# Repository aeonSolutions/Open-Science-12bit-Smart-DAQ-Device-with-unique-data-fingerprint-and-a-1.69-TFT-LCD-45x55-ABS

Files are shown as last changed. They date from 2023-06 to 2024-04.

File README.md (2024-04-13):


 
<a href="https://github.com/sponsors/aeonSolutions">
   
</a>

**Unique Visits** <a href="https://trackgit.com"> trackgit-views </a>



 
</p>

[PCB-Prototyping-Catalogue](https://github.com/aeonSolutions/PCB-Prototyping-Catalogue)  >>  [Laboratory Automation](https://github.com/aeonSolutions/PCB-Prototyping-Catalogue/tree/main/Laboratory%20Automation)  >>  [Smart DAQ](https://github.com/aeonSolutions/PCB-Prototyping-Catalogue/tree/main/Smart%20DAQ)  >> [12-bit Smart DAQs](https://github.com/aeonSolutions/PCB-Prototyping-Catalogue/tree/main/Smart%20DAQ/12-bit) >> 12-bit Smart DAQ Device with unique data fingerprint and a 1.69" TFT LCD  45x55 ABS

<br>

# 12bit Smart DAQ Device with unique data fingerprint and a 1.69" TFT LCD  45x55 ABS
This is the repository for revision of the 12-bit Smart DAQ Device with a unique data fingerprint able to do experimental data upload to any data repository. 

<br>

<p align="center">
<strong> <a href="https://aeonsolutions.github.io/sponsor/sdad/2ch/">Interactive view of the PCB Layout</a> </strong> &nbsp;
  <strong> <a href="https://aeonsolutions.github.io/sponsor/sdad/2ch/circuit_schematic.html">Interactive view of the circuit schematic</a> </strong> <br>
 <sup>Click to view the latest revision</sup>
</p>

<br>

Here one can find the following hardware electronics revisions:
- SDAD rev. 01-2023
- SDAD rev. 02-2023
- SDAD rev. 03-2023
- SDAD rev. 03-2023 B
- SDAD rev. 09-2023
- SDAD rev. 10-2023

<p align="center">
   
</p>

####  Status: Tested. Require improvements. 

**Known faults:**
- PCB copper track optimizations
- components rearrangement for optimization of PCB track inductance 

<br>
 
## Dataverse API C library

This device uses my C++ library to expedite dataverse API integration on smart DAQ devices or elsewhere. Follow the link to its repository:

https://github.com/aeonSolutions/OpenScience-Dataverse-API-C-library

<p align="center">
<a href="https://github.com/aeonSolutions/OpenScience-Dataverse-API-C-library"> 
     
</a>
</p>

<br>
<br>

The photo above is one of the many specimens I purposely fabricated to research self-sensing properties of asphalt mixed with a known content of carbon fibers. This is a 10cm cylinder specimen and on the top is already setup my own design smart #DAQ (get it here on my GitHub ) with the ability to upload LIVE experimental data to a #dataverse.

In the photo above the smart DAQ is installed on an acrylic case and screwed with plastic screws to an acrylic base with the same cross-section area as the specimen to be tested. 
The acrylic base can be bought [here](https://s.click.aliexpress.com/e/_DEGsZaL). And the acrylic case [here](https://s.click.aliexpress.com/e/_Dmudkjt). 

<br>

## CE Ready Logo
This hardware is ready to get a CE marking. To learn more about this marking goto to [Wikipedia here](https://en.wikipedia.org/wiki/CE_marking).

<p align="center">
   
</p>

<br>

### Smart PCB Hardware Specifications
The hardware specifications for the 12bit pcb with dimensions of 23.5x43.5mm can be found [here](https://github.com/aeonSolutions/openScience-Smart-DAQ-to-Upload-Live-Experimental-Data-to-a-Data-Repository/wiki/Smart-DAQ-Specifications).

 **In real life this smart DAQ is able to:**
- connect to all kinds of 3V to 5V Digital sensors;
- connect to all kinds of sensors compatible with the I2C protocol. (max 118 sensors simultaneously)
- measure voltage in the range of  [0;3.3V]
- measure electrical resistance [0; 10^6] Ohm 
- do temperature and humidity compensation on all measurements 
- has a voltage reference sensor for improved accuracy on ADC measurements  
- has a motion sensor to know if anyone moved a specimen during an experiment
- ability to show live experimental data on the 1.69-inch TFT IPS LCD  

<br>
<br>

## PCB circuit Schematic 
The PCB circuit schematic is available in PDF located in the folder "PCB Schematic"
<br>

## KiCad project files
The project files in KiCad are located in the folder "KiCad".
<br>

<p align="center">
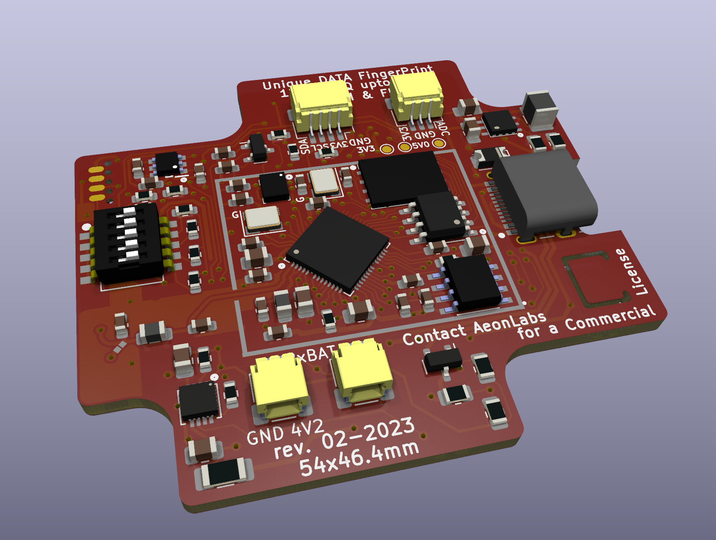
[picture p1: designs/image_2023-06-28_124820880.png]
  
</p>

<br>

## Proof of Concept

To test and validate proposed smart DAQ PCB electronics and its firmware as a solution for LIVE experimental data measurements on any test specimen part of a experimental campaign, This PCB electronics is being used to measure a predefined set of variables/parameters to further study several asphalt mixtures with known carbon fiber weight content in the asphalt matrix. Below is a YouTube link to an unedited short video showing one of the experimental setups.

<p align="center">
   <a href="https://youtu.be/eOA1JPgop0k">
      
   </a> <br>
 <sup>Video on Youtube</sup>
</p>

## Join the Beta Program
Join the beta program to test and debug to provide feedback, ideas, modifications, suggestions, improvements. And in return, write your own article blog or post on social media about it. See participation conditions on the [Wiki](https://github.com/aeonSolutions/PCB-Prototyping-Catalogue/wiki/Beta-Participation-Agreement).  

## Contributing

Bug reports and pull requests are welcome on any of AeonLabs repositories. This project is intended to be a safe, welcoming space for collaboration, and contributors are expected to adhere to the [code of conduct](https://github.com/aeonSolutions/OpenScience-Dataverse-API-C-library/blob/main/CODE_OF_CONDUCT.md).

- Contributing
  - [Your Contributions Matter](https://github.com/aeonSolutions/PCB-Prototyping-Catalogue/wiki/Your-Contributions-Matter)
  - [Contributor Code of Conduct](https://github.com/aeonSolutions/PCB-Prototyping-Catalogue/wiki/Contributor-Code-of-Conduct)

<br>

**[Beta Participation Agreement](https://github.com/aeonSolutions/PCB-Prototyping-Catalogue/wiki/Beta-Participation-Agreement)**

The Beta Participant Agreement is a legal document being executed between you and AeonLabs that outlines the conditions when participating in the Beta Program.

## Coding standards

Please make sure tests pass before committing, and add new tests for new additions.

- Licensing 
  - [AeonLabs Solutions for Open Hardware & Source Development](https://github.com/aeonSolutions/PCB-Prototyping-Catalogue/wiki/AeonLabs-Solutions-for-Open-Hardware-&-Source-Development)

<br>
<br>

## Author

You can get in touch with me on my LinkedIn Profile:

#### Miguel Tomas



You can also follow my GitHub Profile to stay updated about my latest projects: 

<br>

### Be supportive of my dedication and work towards technology education and buy me a cup of coffee
The PCB Desgin Files i provide here for anyone to use are free. If you like this Smart Device or use it, please consider buying me a cup of coffee, a slice of pizza or a book to help me study, eat and think new PCB design files.

<p align="center">
    <a href="https://www.buymeacoffee.com/migueltomas">
        
    </a>
</p>

### Make a donation on Paypal
Make a donation on paypal and get a TAX refund*.

<p align="center">
    <a href="http://paypal.me/mtpsilva">
        
    </a>
</p>

### Support all these open hardware projects and become a Github sponsor  
Liked any of my PCB KiCad Designs? Help and Support my open work to all by becomming a Github sponsor.

<p align="center">
    <a href="https://github.com/aeonSolutions/PCB-Prototyping-Catalogue/blob/main/become_a_sponsor/aeonlabs-github-sponsorship-agreement.docx">
        
    </a>
    <a href="https://github.com/sponsors/aeonSolutions">
        
    </a>
</p>

# 

### License

Before proceeding to download any of AeonLabs software solutions for open-source development and/or PCB hardware electronics development make sure you are choosing the right license for your project. See [AeonLabs Solutions for Open Hardware & Source Development](https://github.com/aeonSolutions/PCB-Prototyping-Catalogue/wiki/AeonLabs-Solutions-for-Open-Hardware-&-Source-Development) for more information.

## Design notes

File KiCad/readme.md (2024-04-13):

[PCB-Prototyping-Catalogue](https://github.com/aeonSolutions/PCB-Prototyping-Catalogue)  >>  [Laboratory Automation](https://github.com/aeonSolutions/PCB-Prototyping-Catalogue/tree/main/Laboratory%20Automation)  >>  [Smart DAQ](https://github.com/aeonSolutions/PCB-Prototyping-Catalogue/tree/main/Smart%20DAQ)  >> [12-bit Smart DAQs](https://github.com/aeonSolutions/PCB-Prototyping-Catalogue/tree/main/Smart%20DAQ/12-bit) >> 12-bit Smart DAQ Device with unique data fingerprint and a 1.69" TFT LCD  45x55 ABS

<div align="right">
 <a href="https://github-com.translate.goog/aeonSolutions/Open-Science-12bit-Smart-DAQ-Device-with-unique-data-fingerprint-and-a-1.69-TFT-LCD-45x55-ABS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">Change language</a>  <br>
Last change 13-04-2024
</div>

<br>

This folder contains the KiCad Project files, for the hardware electronics of the S.D.A.D.  Each KiCad project is available with a [creative commons share alike non-commercial license](https://creativecommons.org/licenses/by-nc-sa/4.0/deed.en) . 

<p align="center">
  <strong> <a href="https://aeonsolutions.github.io/portfolio/hardware_electronics/laboratory/">Interactive web view of the PCB Layout</a> </strong> <br>
 <sup>Click to view the latest revision of the PCB Layout</sup>
</p>

However, they're not fully complete. If you like it and are looking to use it on your projects, you can download the complete Kicad project files with a one-time donation, [click here](https://github.com/sponsors/aeonSolutions) to learn how,  and don't forget to include it in a message the name of the module/hardware electronics you need. <br> Thank you 🙏.

### Support all these open hardware projects and become a GitHub sponsor  
Did you like any of my PCB KiCad Designs? Help and Support my open work to all by becoming a GitHub sponsor.

<p align="center">
    <a href="https://github.com/aeonSolutions/PCB-Prototyping-Catalogue/blob/main/become_a_sponsor/aeonlabs-github-sponsorship-agreement.docx">
        
    </a>
    <a href="https://github.com/sponsors/aeonSolutions">
        
    </a>
</p>

#

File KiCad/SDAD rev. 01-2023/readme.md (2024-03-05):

[PCB-Prototyping-Catalogue](https://github.com/aeonSolutions/PCB-Prototyping-Catalogue)  >>  [Laboratory Automation](https://github.com/aeonSolutions/PCB-Prototyping-Catalogue/tree/main/Laboratory%20Automation)  >>  [Smart DAQ](https://github.com/aeonSolutions/PCB-Prototyping-Catalogue/tree/main/Smart%20DAQ)  >> [12-bit Smart DAQs](https://github.com/aeonSolutions/PCB-Prototyping-Catalogue/tree/main/Smart%20DAQ/12-bit) >> 12-bit Smart DAQ Device with unique data fingerprint and a 1.69" TFT LCD  45x55 ABS

<div align="right">
 <a href="https://github-com.translate.goog/aeonSolutions/Open-Science-12bit-Smart-DAQ-Device-with-unique-data-fingerprint-and-a-1.69-TFT-LCD-45x55-ABS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">Change language</a>  <br>
Last change 05-03-2024
</div>

<br>

This folder contains the KiCad Project files, for the hardware electronics of the S.D.A.D.  Each KiCad project is available with a [creative commons share alike non-commercial license](https://creativecommons.org/licenses/by-nc-sa/4.0/deed.en) . 

<p align="center">
  <strong> <a href="https://aeonsolutions.github.io/sponsor/sdad/2ch/">Interactive web view of the PCB Layout</a> </strong> <br>
 <sup>Click to view the latest revision of the PCB Layout</sup>
</p>

If you like it and use it on your own hardware designs please support this project, [click here](https://github.com/sponsors/aeonSolutions) to learn how. <br> Thank you 🙏. 

### Support all these open hardware projects and become a GitHub sponsor  
Liked any of my PCB KiCad Designs? Help and Support my open work to all by becoming a GitHub sponsor.

<p align="center">
    <a href="https://github.com/aeonSolutions/PCB-Prototyping-Catalogue/blob/main/become_a_sponsor/aeonlabs-github-sponsorship-agreement.docx">
        
    </a>
    <a href="https://github.com/sponsors/aeonSolutions">
        
    </a>
</p>

#

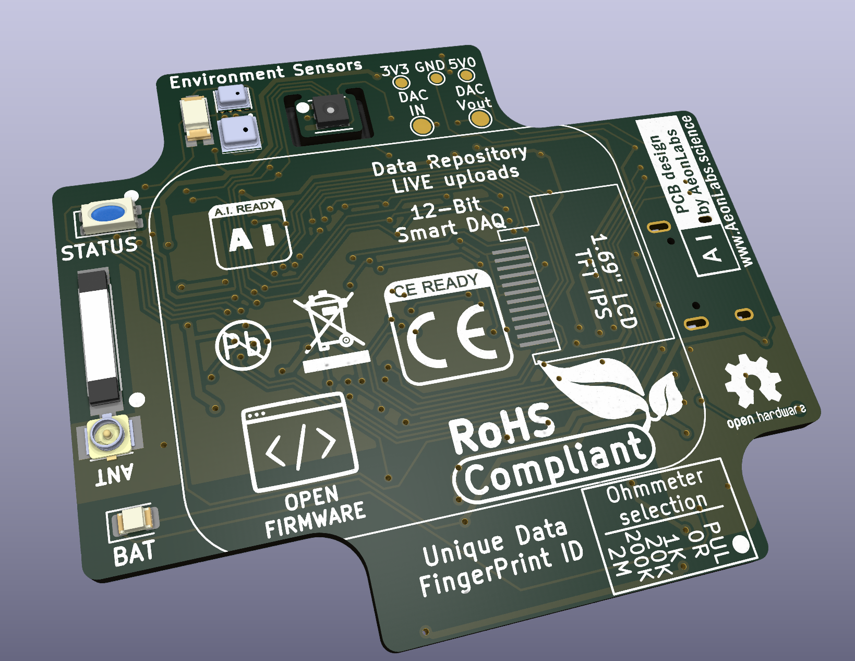
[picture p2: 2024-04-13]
media/revision_10_2023_12bit_lcd.png

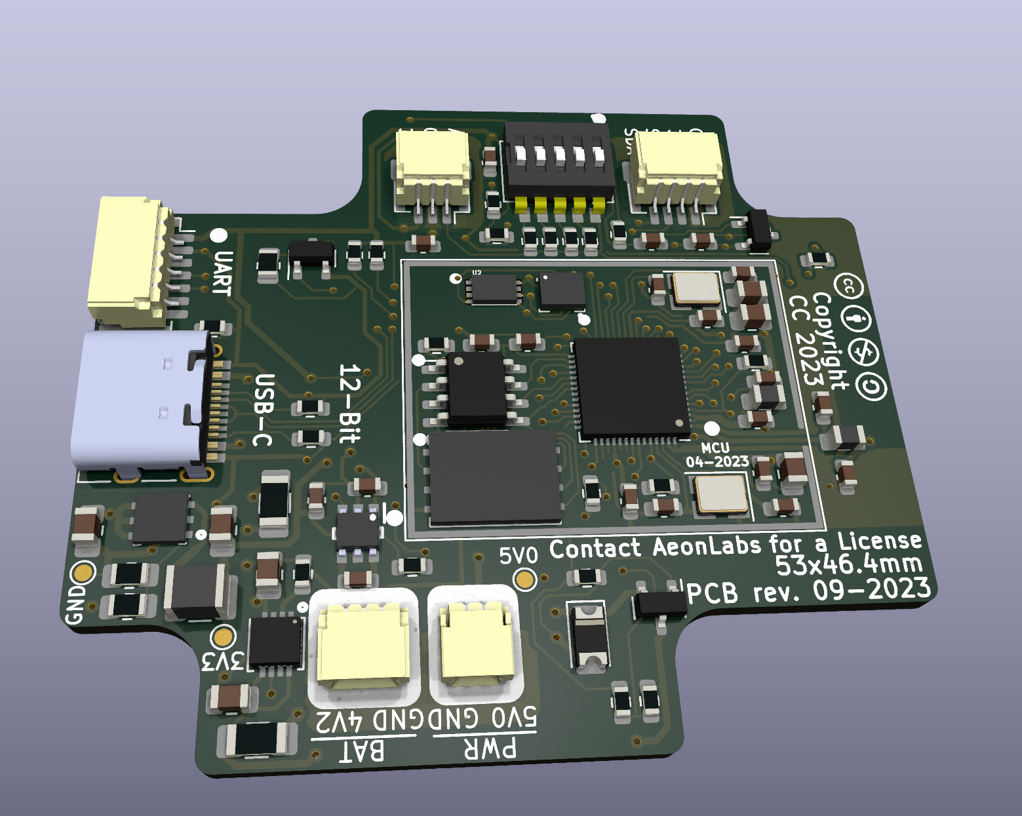
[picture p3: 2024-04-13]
media/revision_10_2023_12bit.png

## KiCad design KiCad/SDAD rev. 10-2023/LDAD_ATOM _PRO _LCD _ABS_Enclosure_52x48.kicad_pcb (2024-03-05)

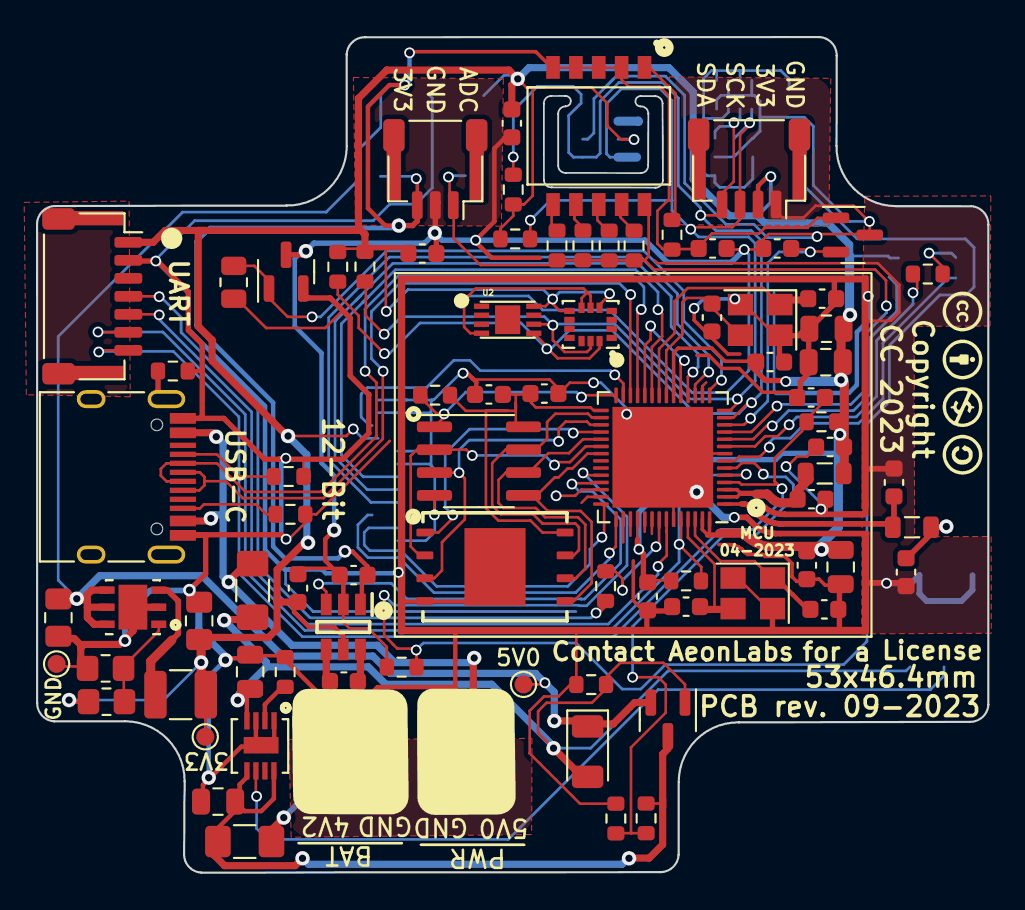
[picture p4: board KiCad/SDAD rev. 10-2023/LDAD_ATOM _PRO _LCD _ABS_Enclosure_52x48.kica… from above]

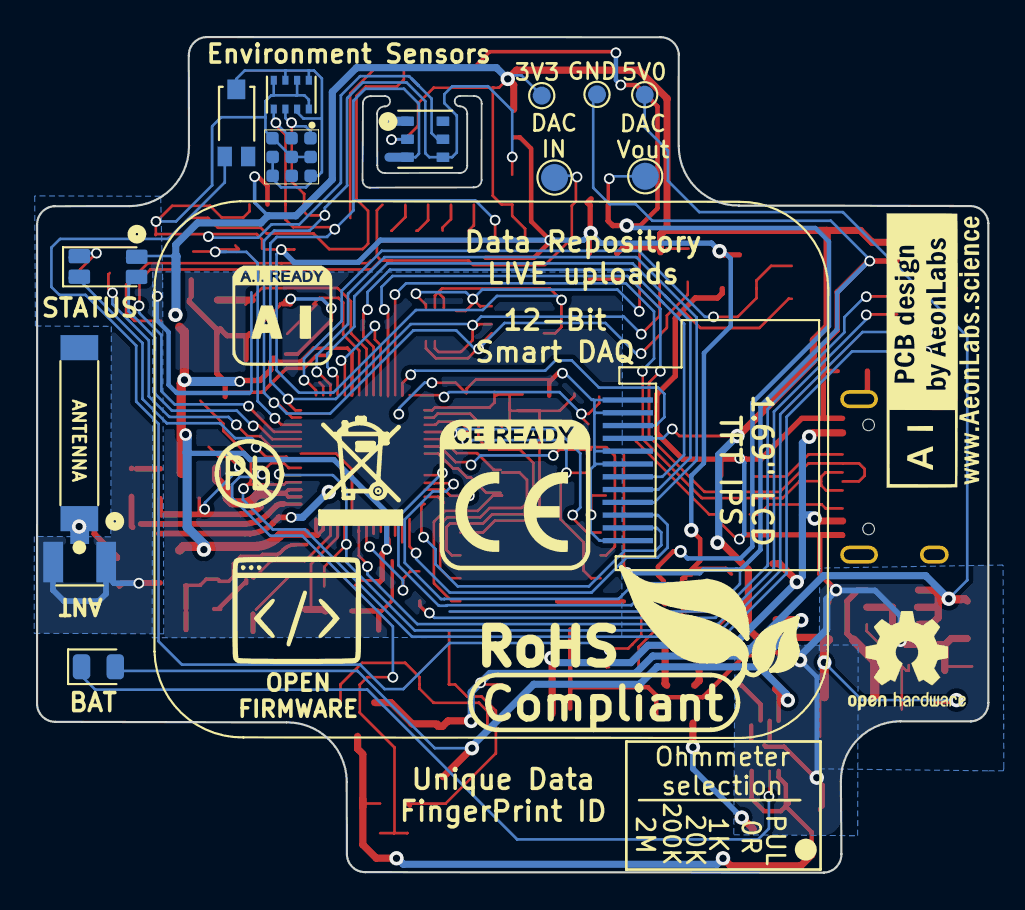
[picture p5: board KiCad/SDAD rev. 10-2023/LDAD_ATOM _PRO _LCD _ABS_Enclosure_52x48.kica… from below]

Board: 2 copper layers, 52.9 x 46.4 mm, 98 parts (15 on the bottom side), 64 nets.

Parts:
ATH20_C1: 100nF; C_0603_1608Metric
ATSHA_C1: 100nF; C_0603_1608Metric
AUR1: AUR9718x_DFN_3x3mm_6_pin; AUR9718 ST1S09 SON95P300X300X100-7N
AUR_C1: 22uF; C_0805_2012Metric_Pad1.18x1.45mm_HandSolder
AUR_C2: 4.7uF; C_0805_2012Metric_Pad1.18x1.45mm_HandSolder
AUR_R1: 75k; R_0805_2012Metric_Pad1.20x1.40mm_HandSolder
AUR_R2: 24k; R_0805_2012Metric_Pad1.20x1.40mm_HandSolder
AUR_l1: 3.3uF; L_1210_3225Metric
BAT_FUSE1: Polyfuse; Fuse_1206_3216Metric_Pad1.42x1.75mm_HandSolder
BAT_SENSE_R1, BAT_SENSE_R2: 100k; R_0603_1608Metric
CN3065_C2: 4.7uF; C_0805_2012Metric
CN3065_R1: 1K8; R_0603_1608Metric
CN3065_STDBY_LED1: LED; LED_0805_2012Metric
CN3965_C1: 22uF; C_0805_2012Metric
DIPSW1: Conn_02x05_Odd_Even; Dip Switch 5pin 1mm SW_DS05-127-2-06BK-SMT-TR
DIP_R1: 4k7; R_0603_1608Metric
DIP_R2: 1k; R_0603_1608Metric
DIP_R3: 20k; R_0603_1608Metric
DIP_R4: 200k; R_0603_1608Metric
DIP_R5: 2M; R_0603_1608Metric
DMP1045U_1: DMP1045U; SOT-23
DMP1045_R1: 10K; R_0603_1608Metric
DMP1045_SCHOT1: D_Schottky; D_1206_3216Metric
EPS1: ESP32-PSRAM_LY68L6400S; SOIC-8_3.9x4.9mm_P1.27mm
ESP32S1: ESP32-S3; QFN-56-1EP_7x7mm_P0.4mm_EP5.6x5.6mm
ESP32_SHIELD1: RFShield_OnePiece; ESP32-S3 GND Shield
ESP_FLASH1: W25Q128JVS; WSON8 FLASH SPI SON127P800X600X80-9N
E_DTR_R1: 10k; R_0603_1608Metric
E_LNA_ANT1: AN9520; 2.4ghZ WIFI ANTENNA AN9520_ANT2-SMD-9.5X2.1X1.0MM
E_LNA_ANT2: U.FL-R-SMT(01); RF Antenna IPEX SMD PCB HRS_U.FL-R-SMT(01)
E_LNA_C1, E_LNA_C2: 2.7pF; C_0603_1608Metric
E_LNA_l1: 1.8nH 5%; L_0805_2012Metric
E_RTS_C1: 100nF; C_0603_1608Metric
E_RTS_R1: 10k; R_0603_1608Metric
E_SPI_C1: 1uF 10% 50V; C_0603_1608Metric
E_SPI_C2: 100nF 10% 16V; C_0603_1608Metric
E_UART_TX_1: 499R; R_0603_1608Metric
E_VDDA_C1: 100nF; C_0603_1608Metric
E_VDDA_C2: 1uF 10% 50V; C_0805_2012Metric
E_VDD_3_C1, E_VDD_3_C2: 10uF 20% 6.3V; C_0805_2012Metric
E_VDD_3_C3, E_VDD_3_C4: 100nF 10% 16V; C_0603_1608Metric
E_VDD_CPU_C1: 100nF 10% 16V; C_0603_1608Metric
E_VDD_L1: 12nH 5%; L_0805_2012Metric
E_VDD_RTC_C1: 100nF 10% 16V; C_0603_1608Metric
E_XTAL32_1: 32.768Mhz 22pF+-10PPM; Crystal_SMD_3225-4Pin_3.2x2.5mm
E_XTAL32_C1, E_XTAL32_C2, E_XTAL40_C1, E_XTAL40_C2: 22pF 5% 50V; C_0603_1608Metric
E_XTAL40_1: 40Mhz 22pF+-10PPM; Crystal_SMD_3225-4Pin_3.2x2.5mm
ExtSW1: Conn_01x03_Female; JST_SH_SM03B-SRSS-TB_1x03-1MP_P1.00mm_Horizontal
ExtSWBAT_PLUG2: Conn_01x03_Female; JST_SH_SM03B-SRSS-TB_1x03-1MP_P1.00mm_Horizontal
HX1: HX4002; HX4002 SOT95 P280X125-6N
HX_C1, HX_C2, HX_C3: 2.2uF; C_0603_1608Metric
I2C_PLUG1: I2C6; JST_SH_SM04B-SRSS-TB_1x04-1MP_P1.00mm_Horizontal
I2C_SCL_R1, I2C_SDA_R1: 10k; R_0603_1608Metric
IC_ENS1: ENS160 Gas Semsor
IMR1, IMR2: 10K; R_0603_1608Metric
IMU1: LSM6DS3; LSM6DS3 Motion Sensor PQFN50P300X250X86-14N
J1: TYPE-C-31-M-12; USB_C_Receptacle_HRO_TYPE-C-31-M-12
JICSP1: Conn_01x07_Socket; JST_SH_SM07B-SRSS-TB_1x07-1MP_P1.00mm_Horizontal
LCD1: Conn_01x12_Male; 1,69 inch LCD IPS TFT
LED1: LED_GBRC; LED_1206_3210_RGB_Metric
LR1: 330R; R_0603_1608Metric
MTRR1: 10k; R_0805_2012Metric
MTRT1: NPN; SOT-23
PSRAM_R1: 100K; R_0603_1608Metric
PWR_FUSE1: Polyfuse; Fuse_1206_3216Metric_Pad1.42x1.75mm_HandSolder
PWR_PLUG1: Screw_Terminal_01x02; JST_SH_SM02B-SRSS-TB_1x02-1MP_P1.00mm_Horizontal
Sign-PbFree: LOGO_PBFREE
Sign-RecycleBin: LOGO_RECYCLEBIN_1
Sign-RoHS: LOGO_ROHS_1
TMPR1: 10K; R_0603_1608Metric
TP1, TP1#2: VIN; TestPoint_Pad_D1.0mm
TP2, TP2#2: VOut; TestPoint_Pad_D1.0mm
TP3, TP3#2: GND; TestPoint_Pad_D1.0mm
U1: MCP1525-TT; SOT-23
U2: ATSHA204A-MAHDA-T; ATSHA204 UDFN-8 DFN200X300X60-9N
U3: Battery_charger_CN3065_QFN8; QFN8 3.1x2.9mm QFNn-8 3x3 SON80P400X400X100-9N
U4: AHT20; AHT20 HT Sensor PSON100P300X300X110-6N
U5: BMP280; XDCR_BMP280
U6: TEMT6000; TEMT6000-SEN
USB_PLUG_R1, USB_PLUG_R3: 5k1; R_0603_1608Metric
USB_PLYG_R2: 150K; R_0603_1608Metric
VOLTAGE_REF_C1, VOLTAGE_REF_C2: 100nF; C_0603_1608Metric

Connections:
3V3: ATH20_C1.2, ATSHA_C1.2, AUR_C1.1, AUR_R1.1, AUR_l1.1, ESP32S1.20 (VDD3P3_RTC), ESP32S1.46 (VDD3P3_CPU), ESP32S1.55 (VDDA), ESP32S1.56 (VDDA), E_DTR_R1.1, E_RTS_R1.1, E_VDDA_C1.2, E_VDDA_C2.2, E_VDD_3_C1.1, E_VDD_3_C2.1, E_VDD_3_C3.1, E_VDD_CPU_C1.1, E_VDD_L1.1, E_VDD_RTC_C1.1, HX1.5 (VIN), HX_C3.2, I2C_PLUG1.2, I2C_SCL_R1.1, I2C_SDA_R1.2, IC_ENS1.4 (VDD), IC_ENS1.5 (VDDIO), IC_ENS1.7 (CS), IMR1.1, IMR2.1, IMU1.5 (VDDIO), IMU1.8 (VDD), JICSP1.1, LCD1.4, LED1.4 (K), TP2.1, TP2#2.1, U2.8 (VCC), U4.2 (VDD), U5.2 (CSB), U5.6 (VDDIO), U5.8 (VDD), U6.COLLECTOR
3V3_PLUG: DIPSW1.3, DIPSW1.5, DIPSW1.7, DIPSW1.9, DIP_R1.2, ExtSW1.3, HX1.1 (VOUT), HX_C1.1, U1.1 (Vin), VOLTAGE_REF_C1.2
ADC_IN_IO04: DIPSW1.2, DIP_R2.1, DIP_R3.1, DIP_R4.1, DIP_R5.1, ESP32S1.11 (GPIO6/ADC1_CH5), ExtSW1.1
BAT_SENSE_IO21: BAT_SENSE_R1.1, BAT_SENSE_R2.2, ESP32S1.6 (GPIO1/ADC1_CH0)
CHIP_EN: ESP32S1.4 (CHIP_PU/RESET), E_RTS_C1.2, E_RTS_R1.2, JICSP1.7
DAC_CALIBRATION: ESP32S1.19 (GPIO14/ADC2_CH3), ESP32S1.24 (GPIO18/ADC2_CH7/DAC_1)
ESP_GPIO0_BOOT-DTR: ESP32S1.5 (GPIO0/BOOT), ESP32S1.52 (GPIO46), E_DTR_R1.2, JICSP1.6
GND: AUR1.2 (GND), AUR1.7 (GND), AUR_C1.2, AUR_C2.2, AUR_R2.2, BAT_SENSE_R1.2, CN3065_C2.1, CN3065_R1.1, CN3965_C1.1, DMP1045_R1.2, EPS1.4 (VSS), ESP32S1.8 (GPIO3/ADC1_CH2), ESP32S1.51 (GPIO45), ESP32S1.57 (GND), ESP32_SHIELD1.1 (Shield), ESP_FLASH1.4 (GND), ESP_FLASH1.9 (GND), E_LNA_ANT2.1 (GND), E_LNA_ANT2.2 (GND), E_LNA_C1.2, E_LNA_C2.2, E_RTS_C1.1, E_SPI_C1.2, E_SPI_C2.2, E_VDDA_C1.1, E_VDDA_C2.1, E_VDD_3_C1.2, E_VDD_3_C2.2, E_VDD_3_C3.2, E_VDD_3_C4.2, E_VDD_CPU_C1.2, E_VDD_RTC_C1.2, E_XTAL32_1.2, E_XTAL32_1.4, E_XTAL32_C1.2, E_XTAL32_C2.2, E_XTAL40_1.2, E_XTAL40_1.4, E_XTAL40_C1.2, E_XTAL40_C2.2, ExtSWBAT_PLUG2.3, J1.B1, J1.B12, JICSP1.2, LCD1.1, LCD1.2, LCD1.5, LCD1.6, LCD1.12, MTRR1.1, MTRT1.2, PWR_PLUG1.1, TP3.1, TP3#2.1, U3.1 (V_Temp), U3.3 (GND), U3.9 (GND), USB_PLUG_R1.2, USB_PLUG_R3.2, USB_PLYG_R2.2
GNDD: ATH20_C1.1, ATSHA_C1.1, ExtSW1.2, HX1.2 (GND), HX_C1.2, HX_C3.1, I2C_PLUG1.1, IC_ENS1.3 (MISO), IC_ENS1.8 (VSS), IC_ENS1.9 (VSS), IMU1.6 (GND), IMU1.7 (GND), MTRT1.3, TMPR1.1, U1.3 (Vss), U2.4 (GND), U4.5 (GND), U5.1 (GND), U5.5 (SDO), U5.7 (GND), VOLTAGE_REF_C1.1, VOLTAGE_REF_C2.1
GPIO8_I2C_SDA: ESP32S1.13 (GPIO8/ADC1_CH7), I2C_PLUG1.4, I2C_SDA_R1.1, IC_ENS1.1 (SDA), IMR1.2, IMU1.14 (SDA), U2.5 (SDA), U4.4 (SDA), U5.3 (SDI)
GPIO9_I2C_SCL: ESP32S1.14 (GPIO9/ADC1_CH8), I2C_PLUG1.3, I2C_SCL_R1.2, IC_ENS1.2 (SCL), IMR2.2, IMU1.13 (SCL), U2.6 (SCL), U4.3 (SCL), U5.4 (SCK)
LCD_CS_IO13: ESP32S1.18 (GPIO13/ADC2_CH2), LCD1.8
LCD_DC_IO17: ESP32S1.23 (GPIO17/ADC2_CH6/DAC_2), LCD1.7
LCD_I2C_SCL_IO12: ESP32S1.17 (GPIO12/ADC2_CH1), LCD1.9
LCD_I2C_SDA_IO38: ESP32S1.43 (GPIO38), LCD1.10
LCD_LED_IO21: ESP32S1.27 (GPIO21), LCD1.3
LCD_RST_IO37: ESP32S1.42 (GPIO37), LCD1.11
LED_B_IO05: ESP32S1.10 (GPIO5/ADC1_CH4), LED1.2 (BA)
LED_G_IO02: ESP32S1.7 (GPIO2/ADC1_CH1), LED1.1 (GA)
LED_R_IO04: ESP32S1.9 (GPIO4/ADC1_CH3), LR1.1
unnamed: AUR1.1 (FB), AUR_R1.2, AUR_R2.1
unnamed: AUR1.3 (SW), AUR_l1.2
unnamed: DIPSW1.1, DIP_R1.1
unnamed: DIPSW1.4, DIP_R2.2
unnamed: DIPSW1.6, DIP_R3.2
unnamed: DIPSW1.8, DIP_R4.2
unnamed: DIPSW1.10, DIP_R5.2
unnamed: ESP32S1.21 (GPIO15/ADC2_CH4/XTAL_32K_P), E_XTAL32_1.3, E_XTAL32_C1.1
unnamed: ESP32S1.22 (GPIO16/ADC2_CH5/XTAL_32K_N), E_XTAL32_1.1, E_XTAL32_C2.1
unnamed: ESP32S1.1 (LNA_IN/RF), E_LNA_C2.1, E_LNA_l1.2
unnamed: ESP32S1.49 (U0TXD/PROG/GPIO43), E_UART_TX_1.2
unnamed: ESP32S1.2 (VDD3P3), ESP32S1.3 (VDD3P3), E_VDD_3_C4.1, E_VDD_L1.2
unnamed: ESP32S1.53 (XTAL_N), E_XTAL40_1.3, E_XTAL40_C2.1
unnamed: ESP32S1.54 (XTAL_P), E_XTAL40_1.1, E_XTAL40_C1.1
unnamed: E_LNA_ANT1.1, E_LNA_ANT2.3 (SIG), E_LNA_C1.1, E_LNA_l1.1
unnamed: HX1.6 (C+), HX_C2.1
unnamed: HX1.4 (C-), HX_C2.2
unnamed: J1.A5 (CC1), USB_PLUG_R3.1
unnamed: J1.B5 (CC2), USB_PLUG_R1.1
unnamed: J1.S1 (SHIELD), USB_PLYG_R2.1
unnamed: LED1.3 (RA), LR1.2
unnamed: CN3065_R1.2, U3.2 (I_SET)
PERIPHERALS_PWR_EN_IO10: ESP32S1.15 (GPIO10/ADC1_CH9), MTRR1.2, MTRT1.1
PLUG_PWR_3V3_EN_IO38: ESP32S1.39 (GPIO34), HX1.3 (EN)
RXD0: ESP32S1.50 (U0RXD/PROG/GPIO44), JICSP1.5
SPICLK: EPS1.6 (SCLK), ESP32S1.33 (SPICLK/GPIO30), ESP_FLASH1.6 (CLK)
SPICS0: ESP32S1.32 (SPICS0/GPIO29), ESP_FLASH1.1 (~CS)
SPICS1: EPS1.1 (~CE), ESP32S1.28 (SPI_CS1/GPIO26), PSRAM_R1.1
SPID: EPS1.5 (SiO0), ESP32S1.35 (SPID/GPIO32), ESP_FLASH1.5 (DI(IO0))
SPIHD: EPS1.7 (SIO3), ESP32S1.30 (SPIHD/GPIO27), ESP_FLASH1.7 (IO3)
SPIQ: EPS1.2 (SIO1), ESP32S1.34 (SPIQ/GPIO31), ESP_FLASH1.2 (DO(IO1))
SPIWP: EPS1.3 (SIO2), ESP32S1.31 (SPIWP/GPIO28), ESP_FLASH1.3 (IO2)
STDBY_LED_G: CN3065_STDBY_LED1.1 (K), U3.6 (LED_DONE)
TEMT6000_IO33: ESP32S1.38 (GPIO33), TMPR1.2, U6.EMITTER
TXD0: E_UART_TX_1.1, JICSP1.4
USB_5V0: CN3065_STDBY_LED1.2 (A), CN3965_C1.2, DMP1045U_1.1, DMP1045_R1.1, DMP1045_SCHOT1.2 (A), PWR_FUSE1.1, U3.4 (VIN)
USB_5V0F: J1.A4, J1.A9, PWR_FUSE1.2, PWR_PLUG1.2
USB_D+: ESP32S1.26 (GPIO20/USB_D+/ADC2_CH9), J1.A6 (DP1), J1.B6 (DP2)
USB_D-: ESP32S1.25 (GPIO19/USB_D-/ADC2_CH8), J1.A7 (DN1), J1.B7 (DN2)
VDD_SPI: EPS1.8 (VCC), ESP32S1.29 (VDD_SPI), ESP_FLASH1.8 (VCC), E_SPI_C1.1, E_SPI_C2.1, PSRAM_R1.2
VIN: AUR1.4 (VIN_SW), AUR1.5 (VIN_A), AUR1.6 (EN), AUR_C2.1, DMP1045U_1.2, DMP1045_SCHOT1.1 (K), TP1.1, TP1#2.1
VIN_BAT: BAT_FUSE1.1, BAT_SENSE_R2.1, CN3065_C2.2, DMP1045U_1.3, U3.5 (BAT+), U3.8 (FB)
VIN_BATF: BAT_FUSE1.2, ExtSWBAT_PLUG2.1
VOLTAGE_REF_IO07: ESP32S1.12 (GPIO7/ADC1_CH6), U1.2 (Vout), VOLTAGE_REF_C2.2

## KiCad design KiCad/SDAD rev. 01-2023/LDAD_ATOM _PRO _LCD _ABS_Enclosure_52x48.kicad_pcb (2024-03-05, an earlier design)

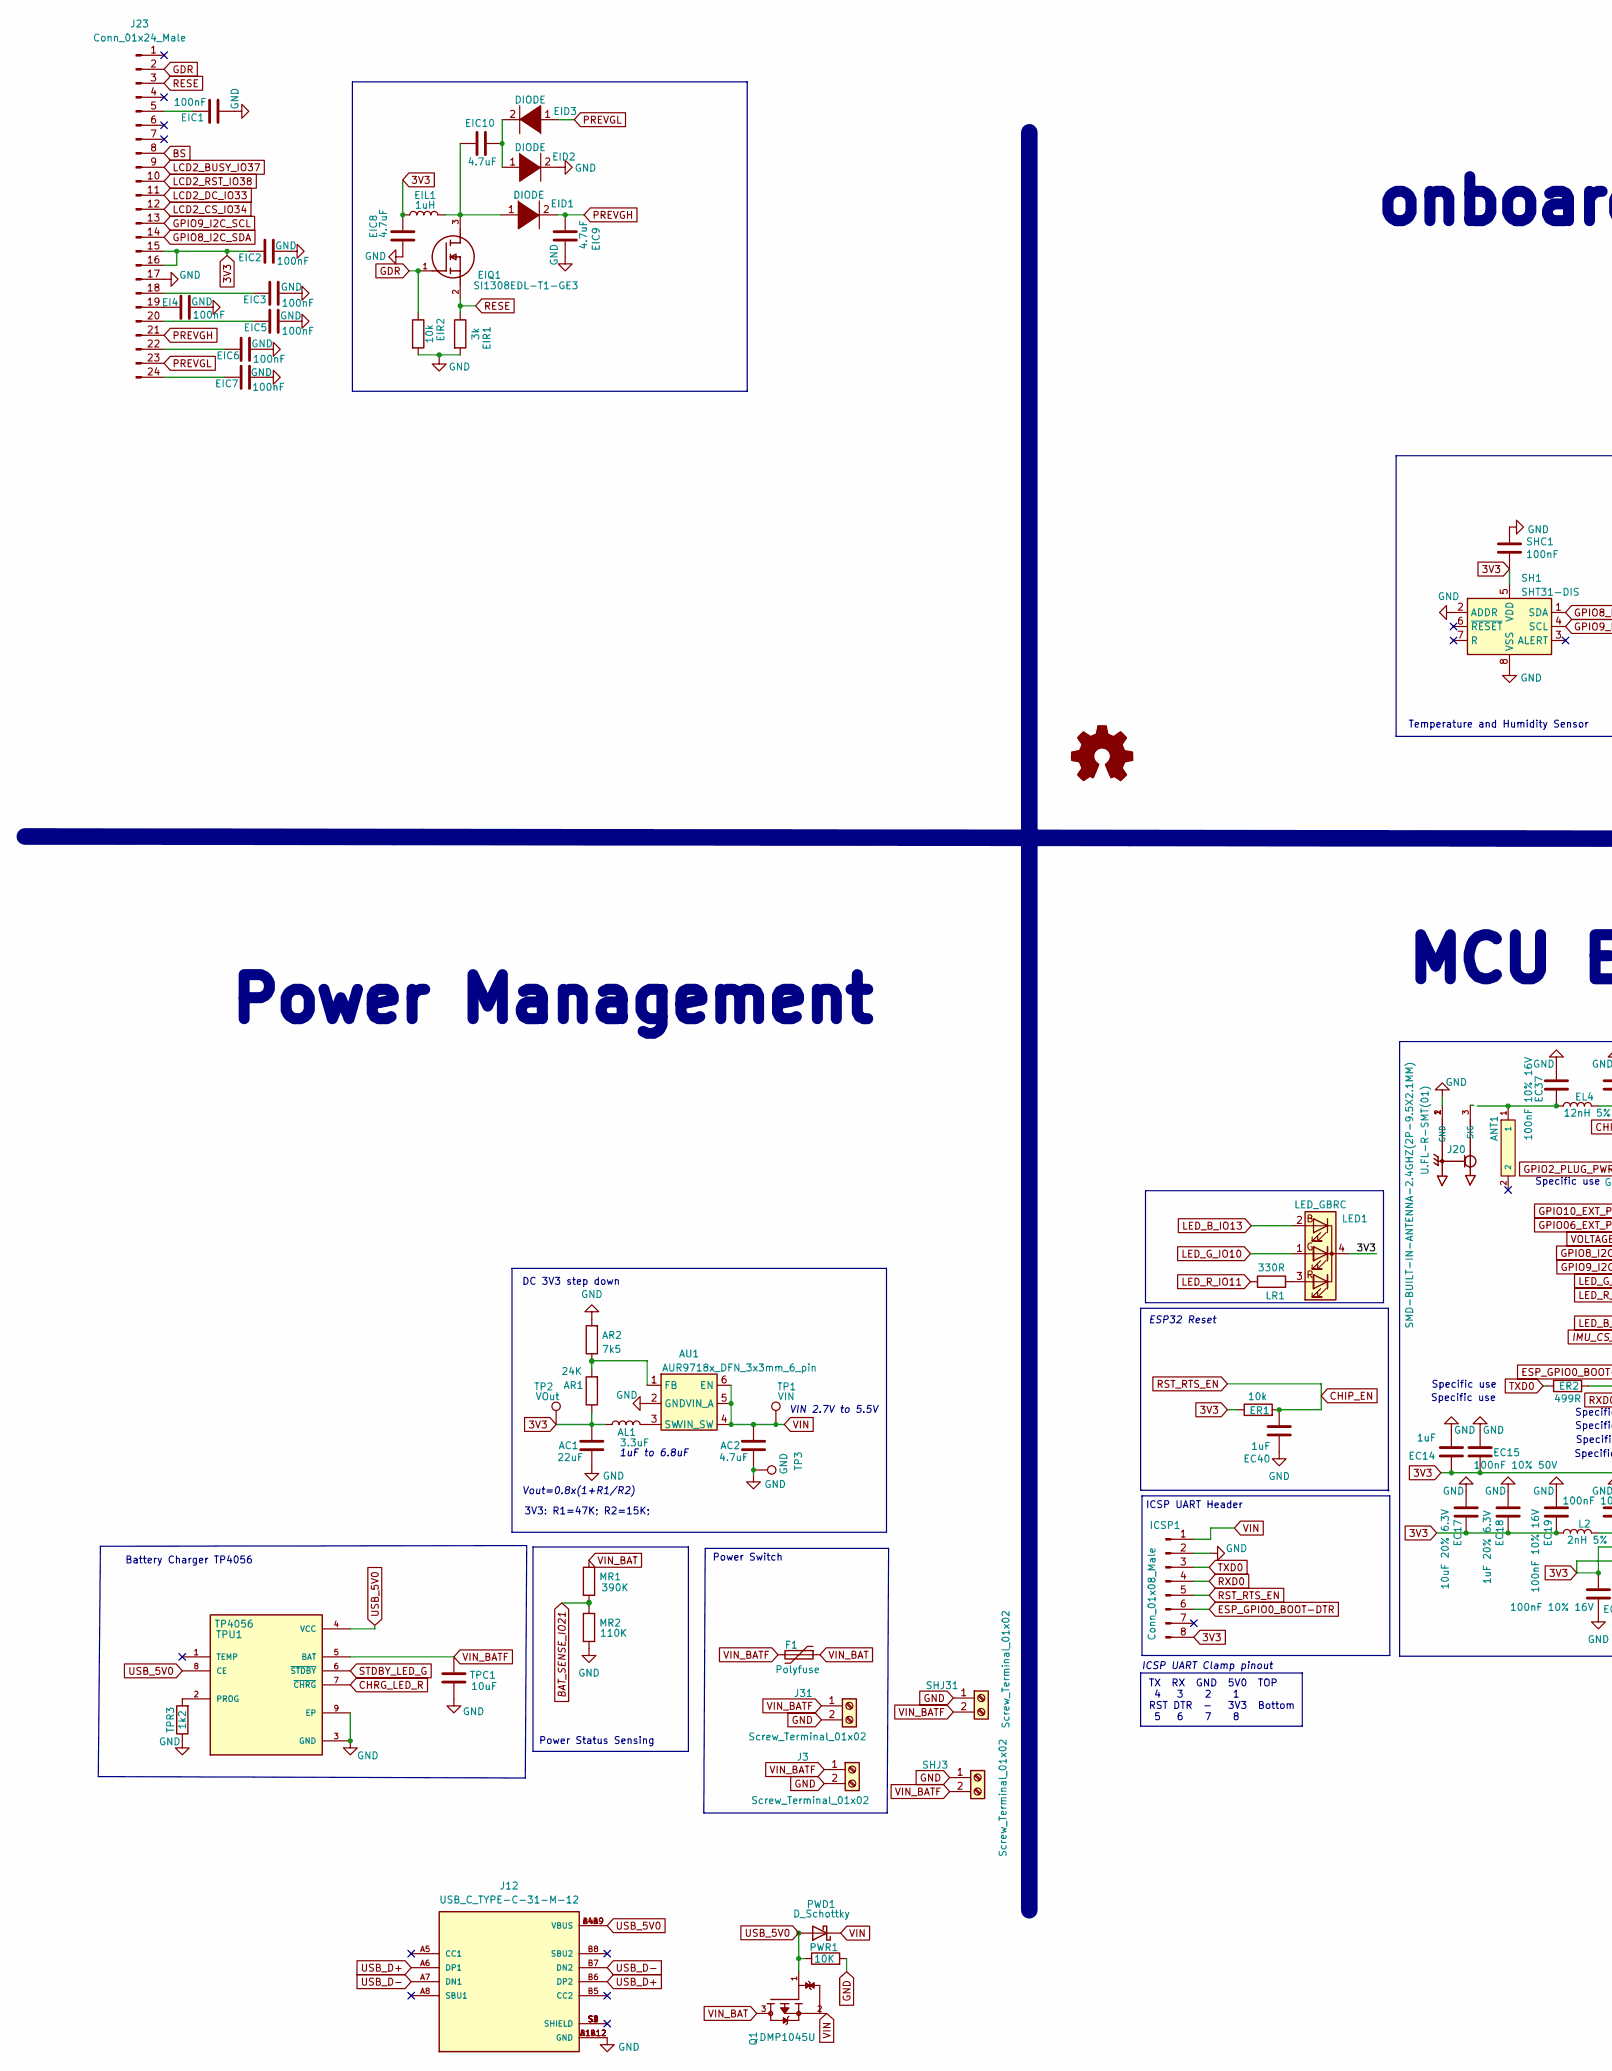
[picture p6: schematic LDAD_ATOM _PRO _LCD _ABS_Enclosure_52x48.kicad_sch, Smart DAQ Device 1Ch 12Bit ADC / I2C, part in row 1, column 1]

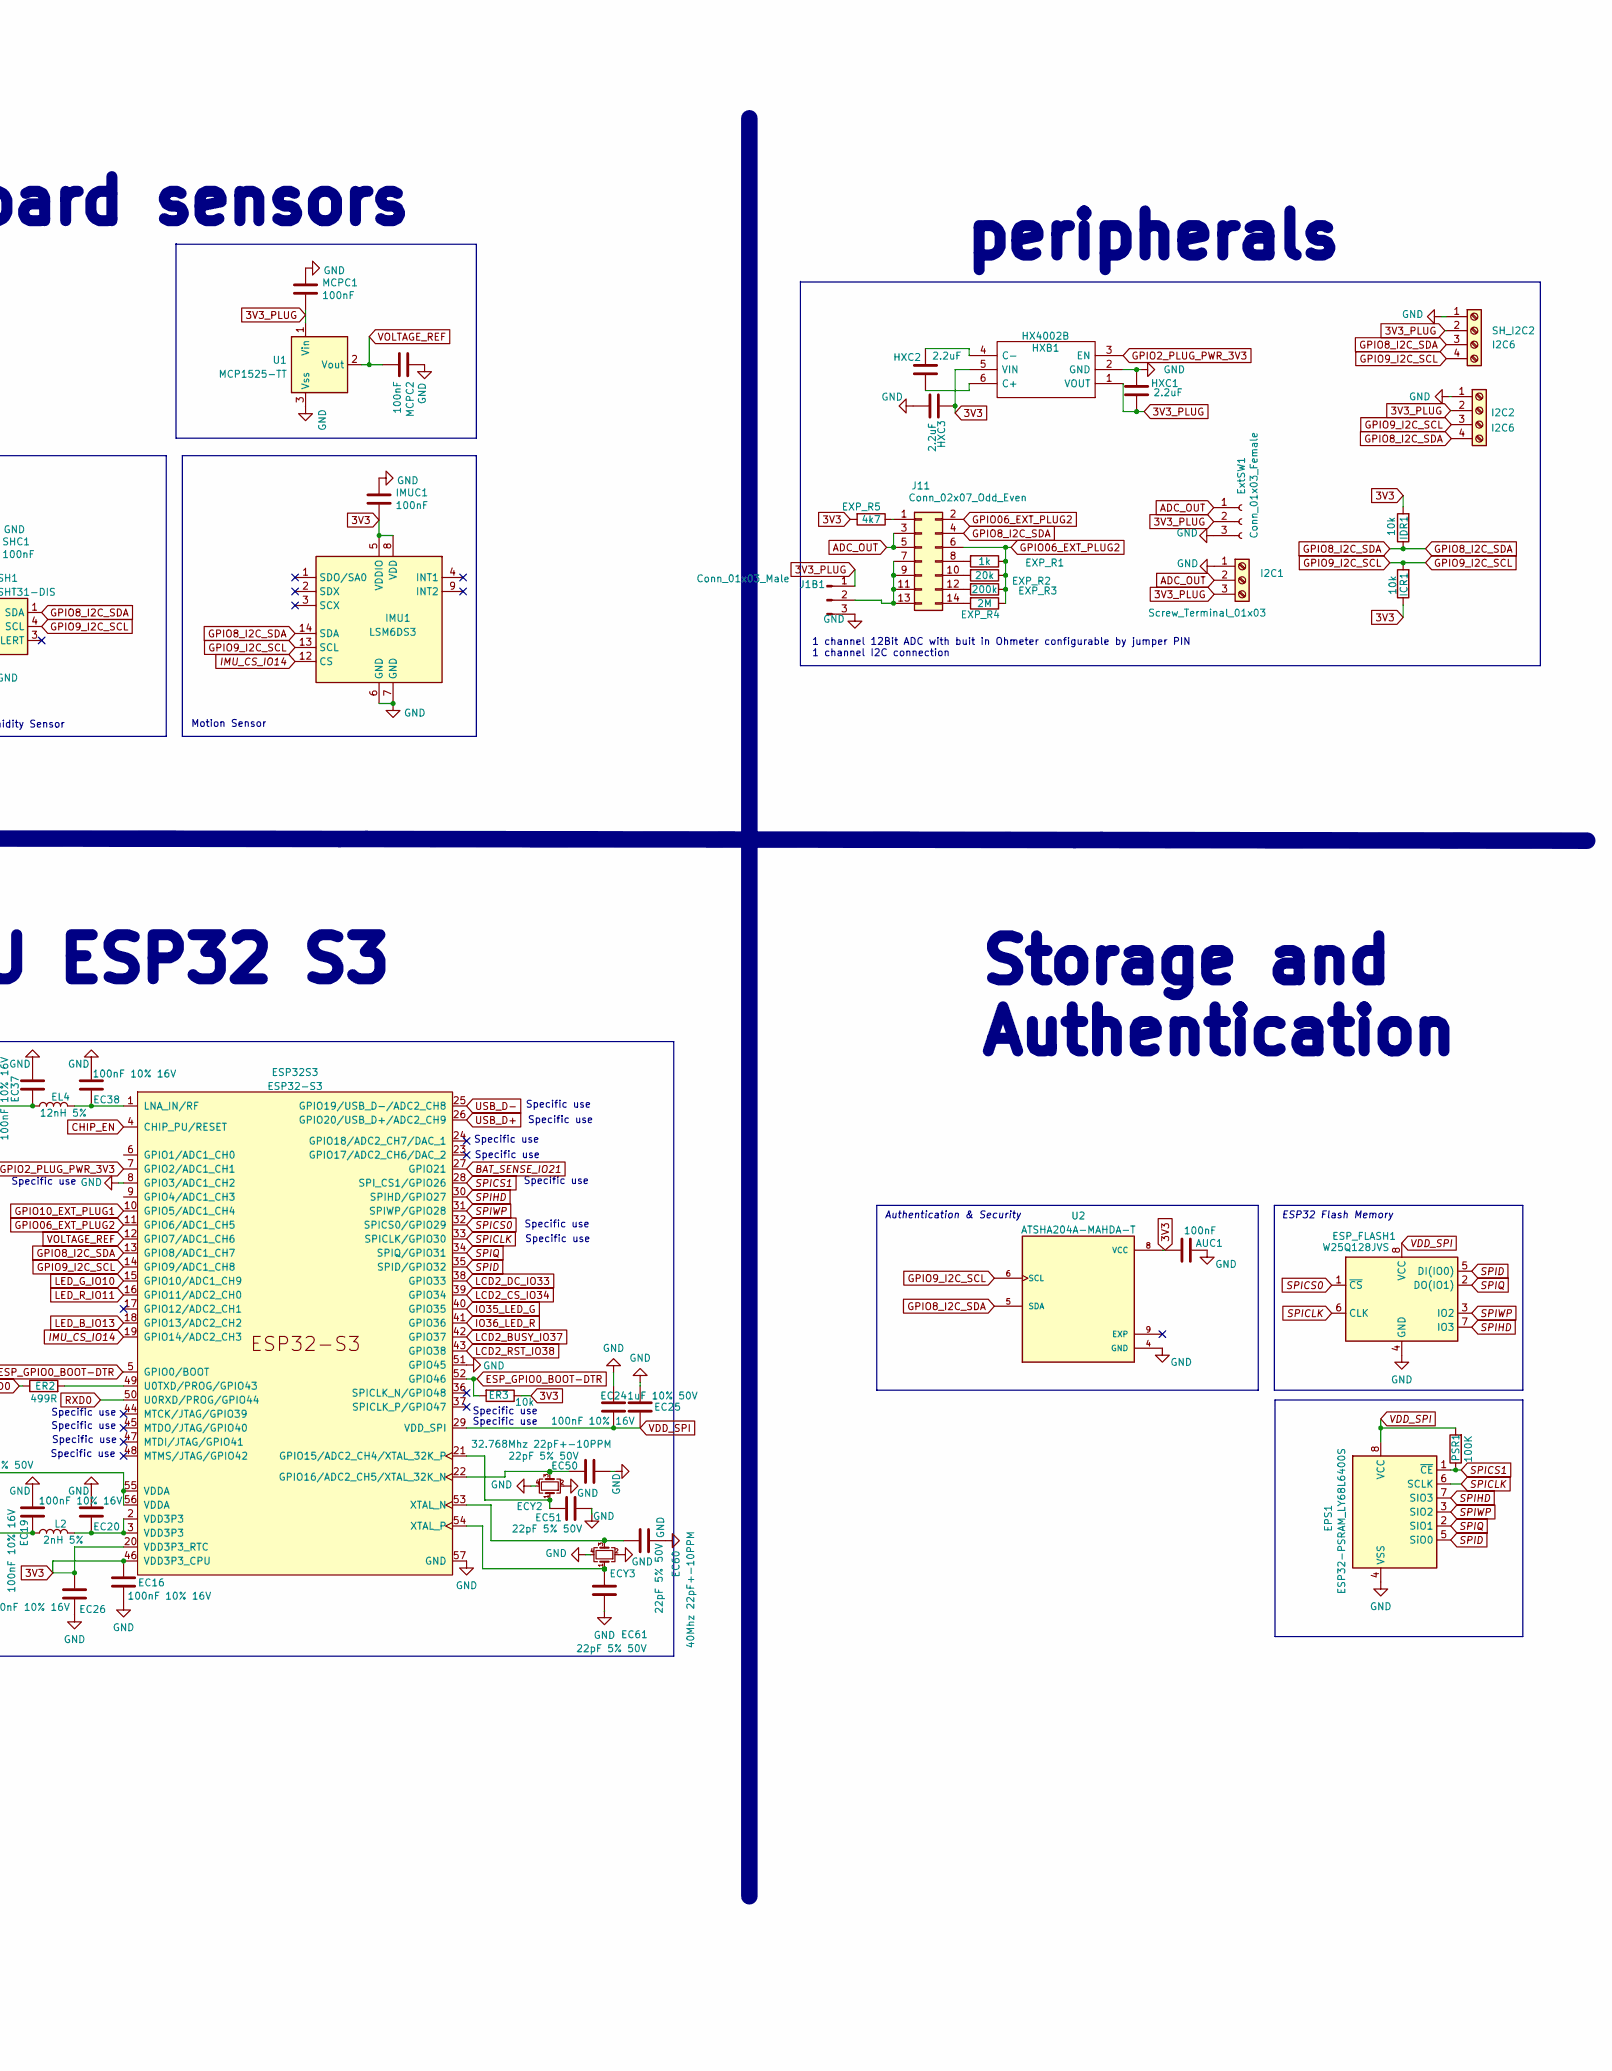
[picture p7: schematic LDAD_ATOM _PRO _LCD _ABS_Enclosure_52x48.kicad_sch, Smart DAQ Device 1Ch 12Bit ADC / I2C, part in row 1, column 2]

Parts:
AC1: 22uF; C_0805_2012Metric_Pad1.18x1.45mm_HandSolder
AC2: 4.7uF; C_0805_2012Metric_Pad1.18x1.45mm_HandSolder
AL1: 3.3uF; L_1210_3225Metric
ANT1: SMD-BUILT-IN-ANTENNA-2.4GHZ(2P-9.5X2.1MM); AN9520_ANT2-SMD-9.5X2.1X1.0MM
AR1: 24K; R_0805_2012Metric_Pad1.20x1.40mm_HandSolder
AR2: 7k5; R_0805_2012Metric_Pad1.20x1.40mm_HandSolder
AU1: AUR9718x_DFN_3x3mm_6_pin; AUR9718 3x3mm 6 pin
AUC1: 100nF; C_0603_1608Metric
EC14, EC40: 1uF; C_0805_2012Metric
EC15: 100nF 10% 50V; C_0603_1608Metric
EC16, EC19, EC20, EC24, EC26, EC37, EC38: 100nF 10% 16V; C_0603_1608Metric
EC17: 10uF 20% 6.3V; C_0603_1608Metric
EC18: 1uF 20% 6.3V; C_0805_2012Metric
EC25: 1uF 10% 50V; C_0805_2012Metric
EC50, EC51, EC60, EC61: 22pF 5% 50V; C_0603_1608Metric
ECY2: 32.768Mhz 22pF+-10PPM; Crystal_SMD_EuroQuartz_MT-4Pin_3.2x2.5mm
ECY3: 40Mhz 22pF+-10PPM; Crystal_SMD_EuroQuartz_MT-4Pin_3.2x2.5mm
EI4: 100nF; C_0603_1608Metric
EIC1, EIC2, EIC3, EIC5, EIC6, EIC7: 100nF; C_0603_1608Metric
EIC8, EIC9, EIC10: 4.7uF; C_0603_1608Metric
EID1, EID2, EID3: DIODE; D_SOD-323
EIL1: 1uH; L_0805_2012Metric
EIQ1: SI1308EDL-T1-GE3; SOT-23; Mouser_Part_Number 78-SI1308EDL-T1-GE3
EIR1: 3k; R_0603_1608Metric
EIR2: 10k; R_0603_1608Metric
EL4: 12nH 5%; L_0805_2012Metric
EPS1: ESP32-PSRAM_LY68L6400S; SOIC-8_3.9x4.9mm_P1.27mm
ER1, ER3: 10k; R_0603_1608Metric
ER2: 499R; R_0603_1608Metric
ESP32S3: ESP32-S3; QFN-56-1EP_7x7mm_P0.4mm_EP5.6x5.6mm
ESP_FLASH1: W25Q128JVS; Flash SPI SON127P800X600X80-9N
EXP_R1: 1k; R_0603_1608Metric
EXP_R2: 20k; R_0603_1608Metric
EXP_R3: 200k; R_0603_1608Metric
EXP_R4: 2M; R_0603_1608Metric
EXP_R5: 4k7; R_0603_1608Metric
ExtSW1: Conn_01x03_Female; JST_SH_BM03B-SRSS-TB_1x03-1MP_P1.00mm_Vertical
F1: Polyfuse; Fuse_1206_3216Metric_Pad1.42x1.75mm_HandSolder
HXB1: HX4002B; HX4002 SOT95 P280X125-6N; Manufacturer_Part_Number HX4002
HXC1, HXC2, HXC3: 2.2uF; C_0603_1608Metric
I2C1: Screw_Terminal_01x03; JST_EH_B3B-EH-A_1x03_P2.50mm_Vertical
I2C2: I2C6; JST_EH_B4B-EH-A_1x04_P2.50mm_Vertical
ICR1: 10k; R_0603_1608Metric
ICSP1: Conn_01x08_Male; SOIC_clipProgSmall
IDR1: 10k; R_0603_1608Metric
IMU1: LSM6DS3; LSM6DS3 PQFN50P300X250X86-14N
IMUC1: 100nF; C_0603_1608Metric
J1B1: Conn_01x03_Male; PinHeader_1x03_P1.27mm_Vertical
J3, J31: Screw_Terminal_01x02; JST_EH_B2B-EH-A_1x02_P2.50mm_Vertical
J11: Conn_02x07_Odd_Even; PinHeader_2x07_P1.27mm_Vertical
J12: USB_C_TYPE-C-31-M-12; USB C HRO_TYPE-C-31-M-12; PARTREV A
J20: U.FL-R-SMT(01); HRS_U.FL-R-SMT(01)
J23: Conn_01x24_Male; 1.54 E-Ink 24 pin
L2: 2nH 5%; L_0805_2012Metric
LED1: LED_GBRC; LED_1206_3210_RGB_Metric
LR1: 330R; R_0603_1608Metric
MCPC1, MCPC2: 100nF; C_0603_1608Metric
MR1: 390K; R_0603_1608Metric
MR2: 110K; R_0603_1608Metric
PSR1: 100K; R_0603_1608Metric
PWD1: D_Schottky; D_1206_3216Metric
PWR1: 10K; R_0603_1608Metric
Q1: DMP1045U; SOT-23; PARTREV 7 - 2
SH1: SHT31-DIS; Sensirion_DFN-8-1EP_2.5x2.5mm_P0.5mm_EP1.1x1.7mm
SHC1: 100nF; C_0603_1608Metric
SHJ3, SHJ31: Screw_Terminal_01x02; JST_SH_SM02B-SRSS-TB_1x02-1MP_P1.00mm_Horizontal
SH_I2C2: I2C6; JST_SH_SM04B-SRSS-TB_1x04-1MP_P1.00mm_Horizontal
TP1: VIN; TestPoint_Pad_D1.0mm
TP2: VOut; TestPoint_Pad_D1.0mm
TP3: GND; TestPoint_Pad_D1.0mm
TPC1: 10uF; C_0805_2012Metric
TPR3: 1k2; R_0603_1608Metric
TPU1: TP4056
U1: MCP1525-TT; SOT-23
U2: ATSHA204A-MAHDA-T; ATSHA204A Auth SOIC8; PART_REV A

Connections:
3V3: AC1.1, AL1.1, AR1.1, AUC1.2, EC14.2, EC15.2, EC16.1, EC17.1, EC18.1, EC19.1, EC26.1, EIC2.1, EIC8.1, EIL1.1, ER1.1, ER3.1, ESP32S3.20 (VDD3P3_RTC), ESP32S3.46 (VDD3P3_CPU), ESP32S3.55 (VDDA), ESP32S3.56 (VDDA), EXP_R5.2, HXB1.5 (VIN), HXC3.2, ICR1.1, ICSP1.8, IDR1.2, IMU1.5 (VDDIO), IMU1.8 (VDD), IMUC1.2, J23.15, J23.16, L2.1, LED1.4 (K), SH1.5 (VDD), SHC1.2, TP2.1, U2.8 (VCC)
3V3_PLUG: ExtSW1.2, HXB1.1 (VOUT), HXC1.1, I2C1.3, I2C2.2, J1B1.1, MCPC1.2, SH_I2C2.2, U1.1 (Vin)
ADC_OUT: ExtSW1.1, I2C1.2, J11.3, J11.5
BAT_SENSE_IO21: ESP32S3.27 (GPIO21), MR1.2, MR2.1
BS: J23.8
CHIP_EN: EC40.2, ER1.2, ESP32S3.4 (CHIP_PU/RESET), ICSP1.5
CHRG_LED_R: TPU1.7 (~CHRG)
ESP_GPIO0_BOOT-DTR: ER3.2, ESP32S3.5 (GPIO0/BOOT), ESP32S3.52 (GPIO46), ICSP1.6
GDR: EIQ1.1, EIR2.1, J23.2
GND: AC1.2, AC2.2, AR2.2, AU1.2 (GND), AUC1.1, EC14.1, EC15.1, EC16.2, EC17.2, EC18.2, EC19.2, EC20.2, EC24.2, EC25.2, EC26.2, EC37.2, EC38.2, EC40.1, EC50.2, EC51.2, EC60.2, EC61.2, ECY2.2, ECY2.4, ECY3.2, ECY3.4, EI4.2, EIC1.2, EIC2.2, EIC3.2, EIC5.2, EIC6.2, EIC7.2, EIC8.2, EIC9.2, EID2.2 (A), EIR1.2, EIR2.2, EPS1.4 (VSS), ESP32S3.8 (GPIO3/ADC1_CH2), ESP32S3.51 (GPIO45), ESP32S3.57 (GND), ESP_FLASH1.4 (GND), ExtSW1.3, HXB1.2 (GND), HXC1.2, HXC3.1, I2C1.1, I2C2.1, ICSP1.2, IMU1.6 (GND), IMU1.7 (GND), IMUC1.1, J1B1.3, J3.2, J12.A1B12 (GND), J12.B1A12 (GND), J20.1 (GND), J20.2 (GND), J23.17, J31.2, MCPC1.1, MCPC2.1, MR2.2, PWR1.2, SH1.2 (ADDR), SH1.8 (VSS), SH1.9 (VSS), SHC1.1, SHJ3.1, SHJ31.1, SH_I2C2.1, TP3.1, TPC1.2, TPR3.1, TPU1.3 (GND), TPU1.9 (EP), U1.3 (Vss), U2.4 (GND)
GPIO2_PLUG_PWR_3V3: ESP32S3.7 (GPIO2/ADC1_CH1), HXB1.3 (EN)
GPIO06_EXT_PLUG2: ESP32S3.11 (GPIO6/ADC1_CH5), EXP_R1.1, EXP_R2.1, EXP_R3.1, EXP_R4.1, J11.2, J11.6
GPIO8_I2C_SDA: ESP32S3.13 (GPIO8/ADC1_CH7), I2C2.4, IDR1.1, IMU1.14 (SDA), J11.4, J23.14, SH1.1 (SDA), SH_I2C2.3, U2.5 (SDA)
GPIO9_I2C_SCL: ESP32S3.14 (GPIO9/ADC1_CH8), I2C2.3, ICR1.2, IMU1.13 (SCL), J23.13, SH1.4 (SCL), SH_I2C2.4, U2.6 (SCL)
GPIO10_EXT_PLUG1: ESP32S3.10 (GPIO5/ADC1_CH4)
IMU_CS_IO14: ESP32S3.19 (GPIO14/ADC2_CH3), IMU1.12 (CS)
IO35_LED_G: ESP32S3.40 (GPIO35)
IO36_LED_R: ESP32S3.41 (GPIO36)
LCD2_BUSY_IO37: ESP32S3.42 (GPIO37), J23.9
LCD2_CS_IO34: ESP32S3.39 (GPIO34), J23.12
LCD2_DC_IO33: ESP32S3.38 (GPIO33), J23.11
LCD2_RST_IO38: ESP32S3.43 (GPIO38), J23.10
LED_B_IO13: ESP32S3.18 (GPIO13/ADC2_CH2), LED1.2 (BA)
LED_G_IO10: ESP32S3.15 (GPIO10/ADC1_CH9), LED1.1 (GA)
LED_R_IO11: ESP32S3.16 (GPIO11/ADC2_CH0), LR1.1
unnamed: AL1.2, AU1.3 (SW)
unnamed: ANT1.1, EC37.1, EL4.1
unnamed: AR1.2, AR2.1, AU1.1 (FB)
unnamed: EC20.1, ESP32S3.2 (VDD3P3), ESP32S3.3 (VDD3P3), L2.2
unnamed: EC38.1, EL4.2, ESP32S3.1 (LNA_IN/RF)
unnamed: EC50.1, ECY2.3, ESP32S3.22 (GPIO16/ADC2_CH5/XTAL_32K_N)
unnamed: EC51.1, ECY2.1, ESP32S3.21 (GPIO15/ADC2_CH4/XTAL_32K_P)
unnamed: EC60.1, ECY3.3, ESP32S3.53 (XTAL_N)
unnamed: EC61.1, ECY3.1, ESP32S3.54 (XTAL_P)
unnamed: EI4.1, J23.19
unnamed: EIC1.1, J23.5
unnamed: EIC3.1, J23.18
unnamed: EIC5.1, J23.20
unnamed: EIC6.1, J23.22
unnamed: EIC7.1, J23.24
unnamed: EIC10.1, EID2.1 (K), EID3.2 (A)
unnamed: EIC10.2, EID1.1 (K), EIL1.2, EIQ1.3
unnamed: ER2.2, ESP32S3.49 (U0TXD/PROG/GPIO43)
unnamed: EXP_R1.2, J11.8
unnamed: EXP_R2.2, J11.10
unnamed: EXP_R3.2, J11.12
unnamed: EXP_R4.2, J11.14
unnamed: EXP_R5.1, J11.1
unnamed: HXB1.4 (C-), HXC2.2
unnamed: HXB1.6 (C+), HXC2.1
unnamed: J1B1.2, J11.7, J11.9, J11.11, J11.13
unnamed: LED1.3 (RA), LR1.2
unnamed: TPR3.2, TPU1.2 (PROG)
PREVGH: EIC9.1, EID1.2 (A), J23.21
PREVGL: EID3.1 (K), J23.23
RESE: EIQ1.2, EIR1.1, J23.3
RXD0: ESP32S3.50 (U0RXD/PROG/GPIO44), ICSP1.4
SPICLK: EPS1.6 (SCLK), ESP32S3.33 (SPICLK/GPIO30), ESP_FLASH1.6 (CLK)
SPICS0: ESP32S3.32 (SPICS0/GPIO29), ESP_FLASH1.1 (~CS)
SPICS1: EPS1.1 (~CE), ESP32S3.28 (SPI_CS1/GPIO26), PSR1.1
SPID: EPS1.5 (SiO0), ESP32S3.35 (SPID/GPIO32), ESP_FLASH1.5 (DI(IO0))
SPIHD: EPS1.7 (SIO3), ESP32S3.30 (SPIHD/GPIO27), ESP_FLASH1.7 (IO3)
SPIQ: EPS1.2 (SIO1), ESP32S3.34 (SPIQ/GPIO31), ESP_FLASH1.2 (DO(IO1))
SPIWP: EPS1.3 (SIO2), ESP32S3.31 (SPIWP/GPIO28), ESP_FLASH1.3 (IO2)
STDBY_LED_G: TPU1.6 (~STDBY)
TXD0: ER2.1, ICSP1.3
USB_5V0: J12.A4B9 (VBUS), J12.B4A9 (VBUS), PWD1.2 (A), PWR1.1, Q1.1, TPU1.4 (VCC), TPU1.8 (CE)
USB_D+: ESP32S3.26 (GPIO20/USB_D+/ADC2_CH9), J12.A6 (DP1), J12.B6 (DP2)
USB_D-: ESP32S3.25 (GPIO19/USB_D-/ADC2_CH8), J12.A7 (DN1), J12.B7 (DN2)
VDD_SPI: EC24.1, EC25.1, EPS1.8 (VCC), ESP32S3.29 (VDD_SPI), ESP_FLASH1.8 (VCC), PSR1.2
VIN: AC2.1, AU1.4 (VIN_SW), AU1.5 (VIN_A), AU1.6 (EN), ICSP1.1, PWD1.1 (K), Q1.2, TP1.1
VIN_BAT: F1.1, MR1.1, Q1.3
VIN_BATF: F1.2, J3.1, J31.1, SHJ3.2, SHJ31.2, TPC1.1, TPU1.5 (BAT)
VOLTAGE_REF: ESP32S3.12 (GPIO7/ADC1_CH6), MCPC2.2, U1.2 (Vout)

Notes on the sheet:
Specific use
3V3: R1=47K; R2=15K;
ICSP UART Header
peripherals
Vout=0.8x(1+R1/R2)
ESP32 Flash Memory
DC 3V3 step down
ESP32 Reset
Temperature and Humidity Sensor
1uF to 6.8uF
Motion Sensor
1 channel 12Bit ADC with buit in Ohmeter configurable by jumper PIN 1 channel I2C connection
onboard sensors
ICSP UART Clamp pinout
Storage and Authentication
Battery Charger TP4056
Power Management
Authentication & Security
VIN 2.7V to 5.5V
Power Switch
MCU ESP32 S3
TX RX GND 5V0 TOP 4 3 2 1 RST DTR - 3V3 Bottom 5 6 7 8
Power Status Sensing

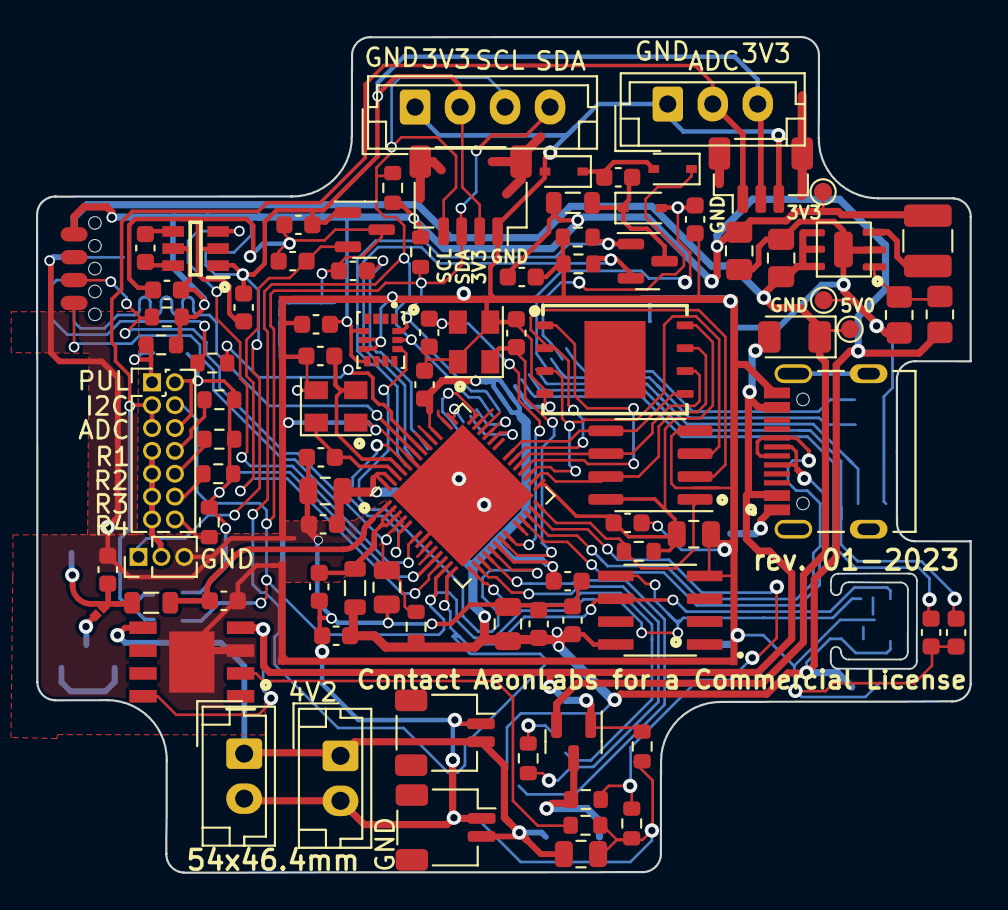
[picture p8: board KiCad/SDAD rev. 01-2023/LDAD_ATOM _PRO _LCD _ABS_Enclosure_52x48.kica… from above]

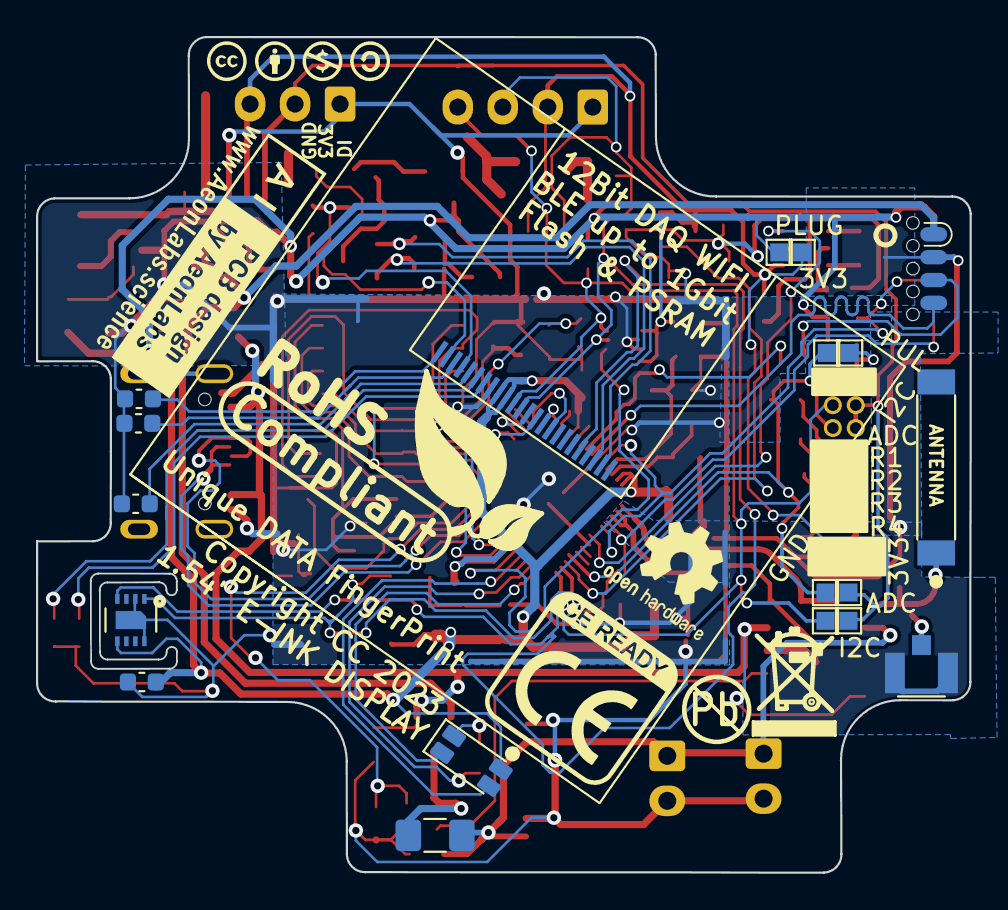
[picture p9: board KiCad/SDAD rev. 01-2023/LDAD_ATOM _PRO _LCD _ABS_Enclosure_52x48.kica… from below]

Board: 2 copper layers, 51.9 x 46.4 mm, 102 parts (14 on the bottom side), 68 nets.

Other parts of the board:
Sign-PbFree: LOGO_PBFREE
Sign-RecycleBin: LOGO_RECYCLEBIN_1
Sign-RoHS: LOGO_ROHS_1

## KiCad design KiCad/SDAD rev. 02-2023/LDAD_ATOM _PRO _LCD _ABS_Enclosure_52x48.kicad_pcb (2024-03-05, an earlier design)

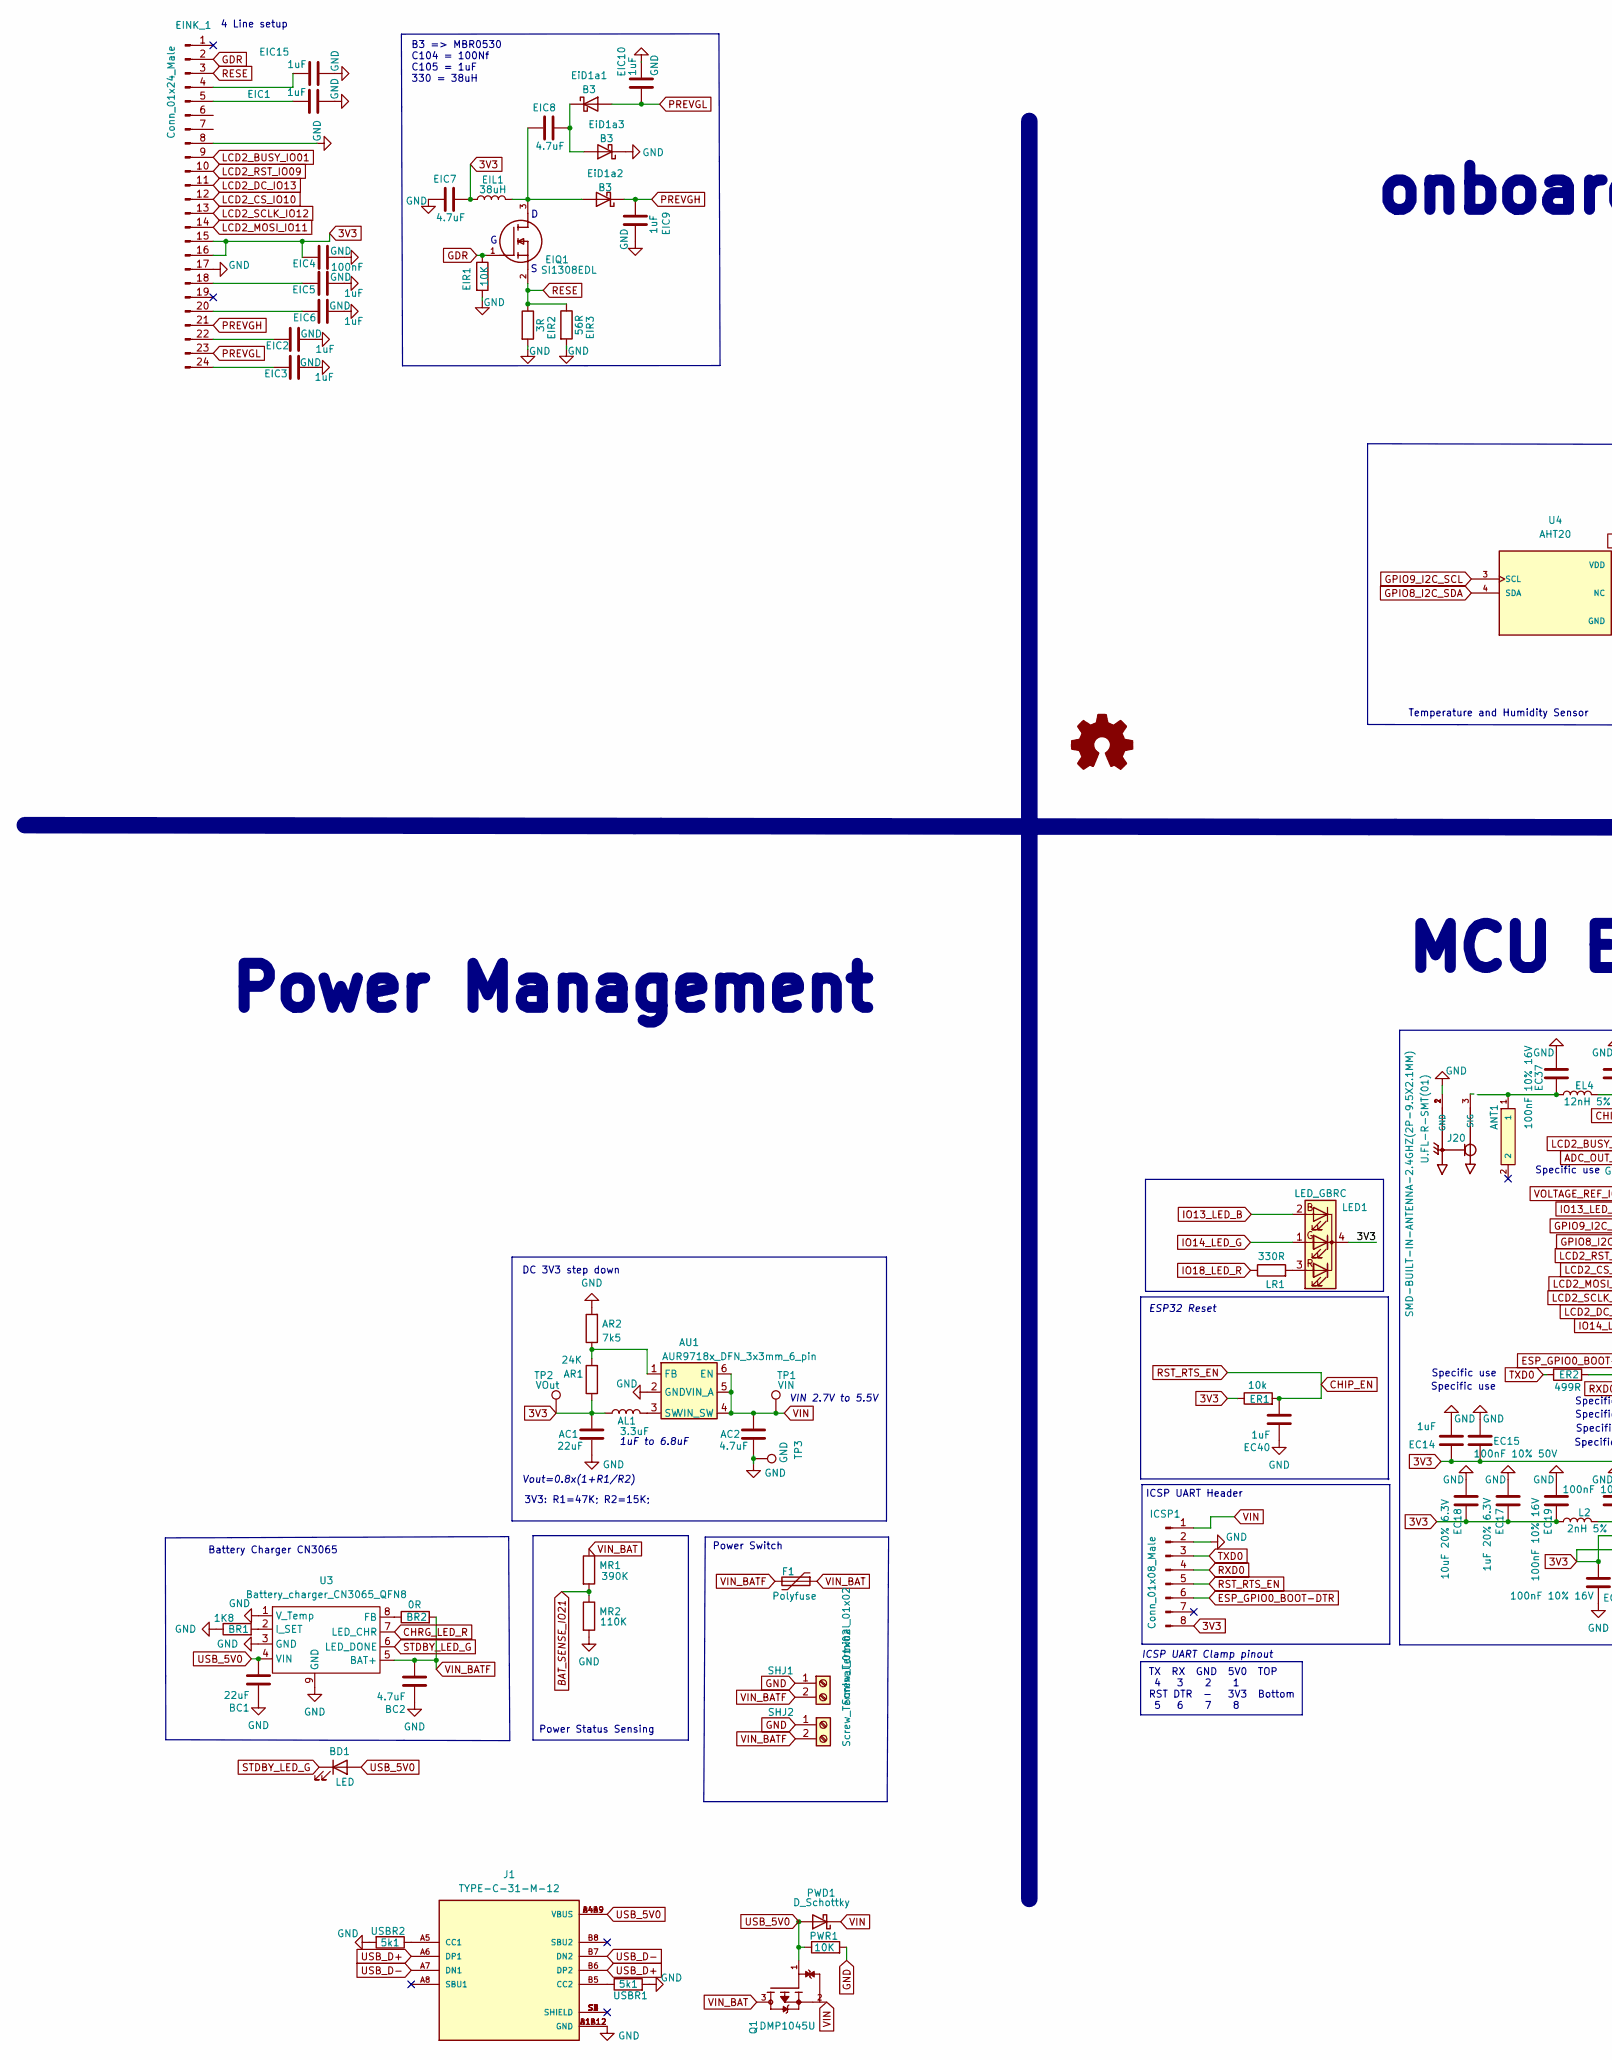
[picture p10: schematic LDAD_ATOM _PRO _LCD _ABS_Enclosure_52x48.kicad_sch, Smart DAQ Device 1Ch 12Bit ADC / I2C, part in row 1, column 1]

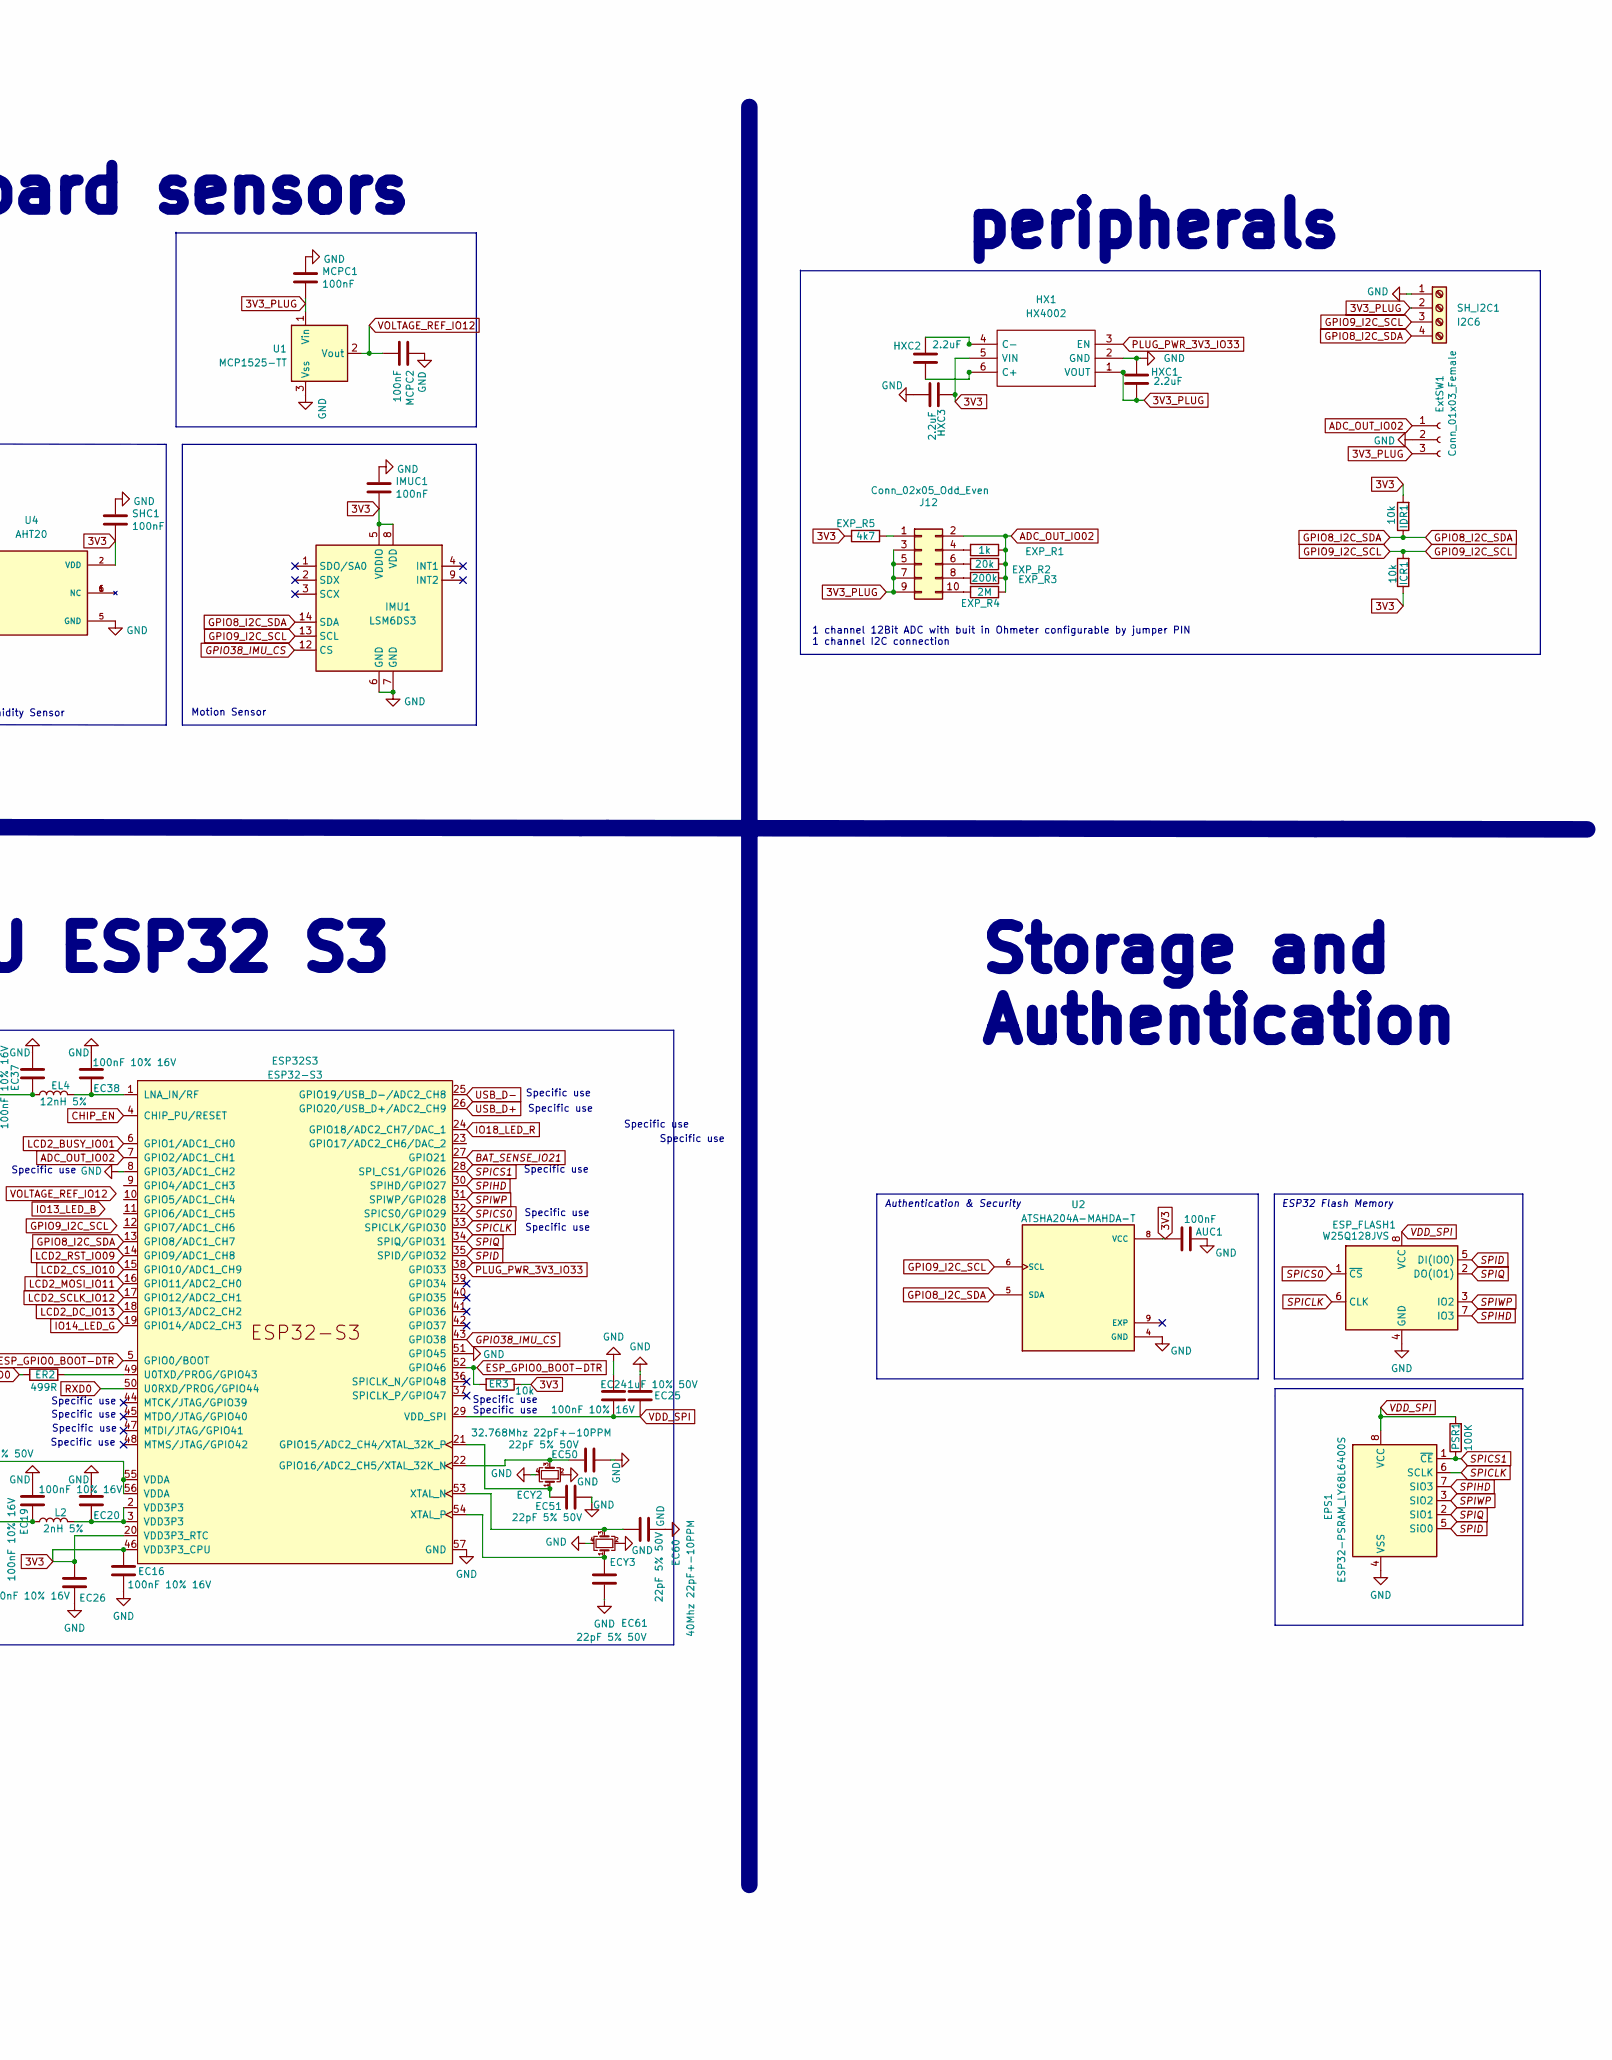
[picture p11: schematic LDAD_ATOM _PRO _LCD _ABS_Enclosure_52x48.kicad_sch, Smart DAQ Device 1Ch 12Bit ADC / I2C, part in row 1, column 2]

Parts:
AC1: 22uF; C_0805_2012Metric_Pad1.18x1.45mm_HandSolder
AC2: 4.7uF; C_0805_2012Metric_Pad1.18x1.45mm_HandSolder
AL1: 3.3uF; L_1210_3225Metric
ANT1: SMD-BUILT-IN-ANTENNA-2.4GHZ(2P-9.5X2.1MM); AN9520_ANT2-SMD-9.5X2.1X1.0MM
AR1: 24K; R_0805_2012Metric_Pad1.20x1.40mm_HandSolder
AR2: 7k5; R_0805_2012Metric_Pad1.20x1.40mm_HandSolder
AU1: AUR9718x_DFN_3x3mm_6_pin; AUR9718 3x3mm 6 pin
AUC1: 100nF; C_0603_1608Metric
BC1: 22uF; C_0805_2012Metric
BC2: 4.7uF; C_0805_2012Metric
BD1: LED; LED_0805_2012Metric
BR1: 1K8; R_0603_1608Metric
BR2: 0R; R_0603_1608Metric
EC14: 1uF; C_0805_2012Metric
EC15: 100nF 10% 50V; C_0603_1608Metric
EC16, EC19, EC20, EC24, EC26, EC37, EC38: 100nF 10% 16V; C_0603_1608Metric
EC17: 1uF 20% 6.3V; C_0603_1608Metric
EC18: 10uF 20% 6.3V; C_0805_2012Metric
EC25: 1uF 10% 50V; C_0603_1608Metric
EC40: 1uF; C_0603_1608Metric
EC50, EC51, EC60, EC61: 22pF 5% 50V; C_0603_1608Metric
ECY2: 32.768Mhz 22pF+-10PPM; Crystal_SMD_EuroQuartz_MT-4Pin_3.2x2.5mm
ECY3: 40Mhz 22pF+-10PPM; Crystal_SMD_EuroQuartz_MT-4Pin_3.2x2.5mm
EIC1, EIC2, EIC3, EIC5, EIC6, EIC9, EIC10, EIC15: 1uF; C_0603_1608Metric
EIC4: 100nF; C_0603_1608Metric
EIC7, EIC8: 4.7uF; C_0603_1608Metric
EIL1: 38uH; L_0805_2012Metric
EINK_1: Conn_01x24_Male; 1.54 E-Ink 24 pin LDAD
EIQ1: SI1308EDL; SOT-323_SC-70; Mouser_Part_Number 78-SI1308EDL-T1-GE3
EIR1: 10K; R_0603_1608Metric
EIR2: 3R; R_0603_1608Metric
EIR3: 56R; R_0603_1608Metric
EL4: 12nH 5%; L_0805_2012Metric
EPS1: ESP32-PSRAM_LY68L6400S; SOIC-8_3.9x4.9mm_P1.27mm
ER1, ER3: 10k; R_0603_1608Metric
ER2: 499R; R_0603_1608Metric
ESP32S3: ESP32-S3; QFN-56-1EP_7x7mm_P0.4mm_EP5.6x5.6mm
ESP_FLASH1: W25Q128JVS; Flash SPI SON127P800X600X80-9N
EXP_R1: 1k; R_0603_1608Metric
EXP_R2: 20k; R_0603_1608Metric
EXP_R3: 200k; R_0603_1608Metric
EXP_R4: 2M; R_0603_1608Metric
EXP_R5: 4k7; R_0603_1608Metric
EiD1a1, EiD1a2, EiD1a3: B3; D_SOD-323
ExtSW1: Conn_01x03_Female; JST_SH_SM03B-SRSS-TB_1x03-1MP_P1.00mm_Horizontal
F1: Polyfuse; Fuse_1206_3216Metric_Pad1.42x1.75mm_HandSolder
HX1: HX4002; HX4002 SOT95 P280X125-6N; Manufacturer_Part_Number HX4002
HXC1, HXC2, HXC3: 2.2uF; C_0603_1608Metric
ICR1: 10k; R_0603_1608Metric
ICSP1: Conn_01x08_Male; SOIC_clipProgSmall
IDR1: 10k; R_0603_1608Metric
IMU1: LSM6DS3; LSM6DS3 PQFN50P300X250X86-14N
IMUC1: 100nF; C_0603_1608Metric
J1: TYPE-C-31-M-12; USB C HRO_TYPE-C-31-M-12; PARTREV A
J12: Conn_02x05_Odd_Even; Dip Switch 5 pin 1.27mm SW_DS05-127-2-06BK-SMT-TR
J20: U.FL-R-SMT(01); HRS_U.FL-R-SMT(01)
L2: 2nH 5%; L_0805_2012Metric
LED1: LED_GBRC; LED_1206_3210_RGB_Metric
LR1: 330R; R_0603_1608Metric
MCPC1, MCPC2: 100nF; C_0603_1608Metric
MR1: 390K; R_0805_2012Metric
MR2: 110K; R_0805_2012Metric
PSR1: 100K; R_0603_1608Metric
PWD1: D_Schottky; D_1206_3216Metric
PWR1: 10K; R_0805_2012Metric
Q1: DMP1045U; SOT-23; PARTREV 7 - 2
SHC1: 100nF; C_0603_1608Metric
SHJ1, SHJ2: Screw_Terminal_01x02; JST_SH_SM02B-SRSS-TB_1x02-1MP_P1.00mm_Horizontal
SH_I2C1: I2C6; JST_SH_SM04B-SRSS-TB_1x04-1MP_P1.00mm_Horizontal
TP1: VIN; TestPoint_Pad_D1.0mm
TP2: VOut; TestPoint_Pad_D1.0mm
TP3: GND; TestPoint_Pad_D1.0mm
U1: MCP1525-TT; SOT-23
U2: ATSHA204A-MAHDA-T; ATSHA204A Auth SOIC8; PART_REV A
U3: Battery_charger_CN3065_QFN8; QFN8 3.1x2.9mm QFNn-8 3x3 SON80P400X400X100-9N
U4: AHT20; AHT20 - PSON100P300X300X110-6N; PARTREV V1.0
USBR1, USBR2: 5k1; R_0603_1608Metric

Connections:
3V3: AC1.1, AL1.1, AR1.1, AUC1.2, EC14.2, EC15.2, EC16.1, EC17.1, EC18.1, EC19.1, EC26.1, EIC4.1, EIC7.1, EIL1.1, EINK_1.15, EINK_1.16, ER1.1, ER3.1, ESP32S3.20 (VDD3P3_RTC), ESP32S3.46 (VDD3P3_CPU), ESP32S3.55 (VDDA), ESP32S3.56 (VDDA), EXP_R5.2, HX1.5 (VIN), HXC3.2, ICR1.1, ICSP1.8, IDR1.2, IMU1.5 (VDDIO), IMU1.8 (VDD), IMUC1.2, L2.1, LED1.4 (K), SHC1.2, TP2.1, U2.8 (VCC), U4.2 (VDD); also elsewhere on the board
3V3_PLUG: ExtSW1.3, HX1.1 (VOUT), HXC1.1, J12.3, J12.5, J12.7, J12.9, MCPC1.2, SH_I2C1.2, U1.1 (Vin)
ADC_OUT_IO02: ESP32S3.7 (GPIO2/ADC1_CH1), EXP_R1.1, EXP_R2.1, EXP_R3.1, EXP_R4.1, ExtSW1.1, J12.2
BAT_SENSE_IO21: ESP32S3.27 (GPIO21), MR1.2, MR2.1
CHIP_EN: EC40.2, ER1.2, ESP32S3.4 (CHIP_PU/RESET), ICSP1.5
CHRG_LED_R: U3.7 (LED_CHR)
ESP_GPIO0_BOOT-DTR: ER3.2, ESP32S3.5 (GPIO0/BOOT), ESP32S3.52 (GPIO46), ICSP1.6
GDR: EINK_1.2, EIQ1.1, EIR1.1; also elsewhere on the board
GND: AC1.2, AC2.2, AR2.2, AU1.2 (GND), AUC1.1, BC1.1, BC2.1, BR1.1, EC14.1, EC15.1, EC16.2, EC17.2, EC18.2, EC19.2, EC20.2, EC24.2, EC25.2, EC26.2, EC37.2, EC38.2, EC40.1, EC50.2, EC51.2, EC60.2, EC61.2, ECY2.2, ECY2.4, ECY3.2, ECY3.4, EIC1.2, EIC2.2, EIC3.2, EIC4.2, EIC5.2, EIC6.2, EIC7.2, EIC9.2, EIC10.2, EIC15.2, EINK_1.8, EINK_1.17, EIR1.2, EIR2.2, EIR3.2, EPS1.4 (VSS), ESP32S3.8 (GPIO3/ADC1_CH2), ESP32S3.51 (GPIO45), ESP32S3.57 (GND), ESP_FLASH1.4 (GND), EiD1a3.1 (K), ExtSW1.2, HX1.2 (GND), HXC1.2, HXC3.1, ICSP1.2, IMU1.6 (GND), IMU1.7 (GND), IMUC1.1, J1.A1B12 (GND), J1.B1A12 (GND), J20.1 (GND), J20.2 (GND), MCPC1.1, MCPC2.1, MR2.2, PWR1.2, SHC1.1, SHJ1.1, SHJ2.1, SH_I2C1.1, TP3.1, U1.3 (Vss), U2.4 (GND), U3.1 (V_Temp), U3.3 (GND), U3.9 (GND), U4.5 (GND), USBR1.2, USBR2.2; also elsewhere on the board
GPIO8_I2C_SDA: ESP32S3.13 (GPIO8/ADC1_CH7), IDR1.1, IMU1.14 (SDA), SH_I2C1.4, U2.5 (SDA), U4.4 (SDA); also elsewhere on the board
GPIO9_I2C_SCL: ICR1.2, IMU1.13 (SCL), SH_I2C1.3, U2.6 (SCL), U4.3 (SCL); also elsewhere on the board
GPIO38_IMU_CS: ESP32S3.43 (GPIO38), IMU1.12 (CS)
IO13_LED_B: LED1.2 (BA)
IO14_LED_G: ESP32S3.19 (GPIO14/ADC2_CH3), LED1.1 (GA)
IO18_LED_R: ESP32S3.24 (GPIO18/ADC2_CH7/DAC_1), LR1.1
LCD2_BUSY_IO01: EINK_1.9, ESP32S3.6 (GPIO1/ADC1_CH0); also elsewhere on the board
LCD2_CS_IO10: EINK_1.12, ESP32S3.15 (GPIO10/ADC1_CH9); also elsewhere on the board
LCD2_DC_IO13: EINK_1.11, ESP32S3.18 (GPIO13/ADC2_CH2); also elsewhere on the board
LCD2_MOSI_IO11: EINK_1.14, ESP32S3.16 (GPIO11/ADC2_CH0); also elsewhere on the board
LCD2_RST_IO09: EINK_1.10, ESP32S3.14 (GPIO9/ADC1_CH8); also elsewhere on the board
LCD2_SCLK_IO12: EINK_1.13, ESP32S3.17 (GPIO12/ADC2_CH1); also elsewhere on the board
unnamed: ANT1.1, EC37.1, EL4.1
unnamed: AR1.2, AR2.1, AU1.1 (FB)
unnamed: AL1.2, AU1.3 (SW)
unnamed: EC20.1, ESP32S3.2 (VDD3P3), ESP32S3.3 (VDD3P3), L2.2
unnamed: EC51.1, ECY2.1, ESP32S3.21 (GPIO15/ADC2_CH4/XTAL_32K_P)
unnamed: EC50.1, ECY2.3, ESP32S3.22 (GPIO16/ADC2_CH5/XTAL_32K_N)
unnamed: EC38.1, EL4.2, ESP32S3.1 (LNA_IN/RF)
unnamed: ER2.2, ESP32S3.49 (U0TXD/PROG/GPIO43)
unnamed: EC60.1, ECY3.3, ESP32S3.53 (XTAL_N)
unnamed: EC61.1, ECY3.1, ESP32S3.54 (XTAL_P)
unnamed: EIC8.1, EiD1a1.1 (K), EiD1a3.2 (A)
unnamed: EIC8.2, EIL1.2, EIQ1.3, EiD1a2.2 (A)
unnamed: HX1.6 (C+), HXC2.1
unnamed: HX1.4 (C-), HXC2.2
unnamed: J1.A5 (CC1), USBR2.1
unnamed: J1.B5 (CC2), USBR1.1
unnamed 37: EIC15.1, EINK_1.4; also elsewhere on the board
unnamed 38: EIC1.1, EINK_1.5; also elsewhere on the board
unnamed 39: EIC5.1, EINK_1.18; also elsewhere on the board
unnamed 40: EIC6.1, EINK_1.20; also elsewhere on the board
unnamed 41: EIC2.1, EINK_1.22; also elsewhere on the board
unnamed 42: EIC3.1, EINK_1.24; also elsewhere on the board
unnamed: EXP_R5.1, J12.1
unnamed: EXP_R1.2, J12.4
unnamed: EXP_R2.2, J12.6
unnamed: EXP_R3.2, J12.8
unnamed: EXP_R4.2, J12.10
unnamed: LED1.3 (RA), LR1.2
unnamed: BR2.1, U3.8 (FB)
unnamed: BR1.2, U3.2 (I_SET)
PLUG_PWR_3V3_IO33: ESP32S3.38 (GPIO33), HX1.3 (EN)
PREVGH: EIC9.1, EINK_1.21, EiD1a2.1 (K); also elsewhere on the board
PREVGL: EIC10.1, EINK_1.23, EiD1a1.2 (A); also elsewhere on the board
RESE: EINK_1.3, EIQ1.2, EIR2.1, EIR3.1; also elsewhere on the board
RXD0: ESP32S3.50 (U0RXD/PROG/GPIO44), ICSP1.4
SPICLK: EPS1.6 (SCLK), ESP32S3.33 (SPICLK/GPIO30), ESP_FLASH1.6 (CLK)
SPICS0: ESP32S3.32 (SPICS0/GPIO29), ESP_FLASH1.1 (~CS)
SPICS1: EPS1.1 (~CE), ESP32S3.28 (SPI_CS1/GPIO26), PSR1.1
SPID: EPS1.5 (SiO0), ESP32S3.35 (SPID/GPIO32), ESP_FLASH1.5 (DI(IO0))
SPIHD: EPS1.7 (SIO3), ESP32S3.30 (SPIHD/GPIO27), ESP_FLASH1.7 (IO3)
SPIQ: EPS1.2 (SIO1), ESP32S3.34 (SPIQ/GPIO31), ESP_FLASH1.2 (DO(IO1))
SPIWP: EPS1.3 (SIO2), ESP32S3.31 (SPIWP/GPIO28), ESP_FLASH1.3 (IO2)
STDBY_LED_G: BD1.1 (K), U3.6 (LED_DONE)
TXD0: ER2.1, ICSP1.3
USB_5V0: BC1.2, BD1.2 (A), J1.A4B9 (VBUS), J1.B4A9 (VBUS), PWD1.2 (A), PWR1.1, Q1.1, U3.4 (VIN)
USB_D+: ESP32S3.26 (GPIO20/USB_D+/ADC2_CH9), J1.A6 (DP1), J1.B6 (DP2)
USB_D-: ESP32S3.25 (GPIO19/USB_D-/ADC2_CH8), J1.A7 (DN1), J1.B7 (DN2)
VDD_SPI: EC24.1, EC25.1, EPS1.8 (VCC), ESP32S3.29 (VDD_SPI), ESP_FLASH1.8 (VCC), PSR1.2
VIN: AC2.1, AU1.4 (VIN_SW), AU1.5 (VIN_A), AU1.6 (EN), ICSP1.1, PWD1.1 (K), Q1.2, TP1.1
VIN_BAT: F1.1, MR1.1, Q1.3
VIN_BATF: BC2.2, BR2.2, F1.2, SHJ1.2, SHJ2.2, U3.5 (BAT+)
VOLTAGE_REF_IO12: MCPC2.2, U1.2 (Vout)

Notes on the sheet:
Specific use
3V3: R1=47K; R2=15K;
ICSP UART Header
peripherals
Vout=0.8x(1+R1/R2)
ESP32 Flash Memory
DC 3V3 step down
ESP32 Reset
Temperature and Humidity Sensor
4 Line setup
1uF to 6.8uF
Motion Sensor
1 channel 12Bit ADC with buit in Ohmeter configurable by jumper PIN 1 channel I2C connection
onboard sensors
ICSP UART Clamp pinout
Storage and Authentication
Battery Charger CN3065
Power Management
Authentication & Security
VIN 2.7V to 5.5V
Power Switch
MCU ESP32 S3
TX RX GND 5V0 TOP 4 3 2 1 RST DTR - 3V3 Bottom 5 6 7 8
B3 => MBR0530 C104 = 100Nf C105 = 1uF 330 = 38uH
Power Status Sensing

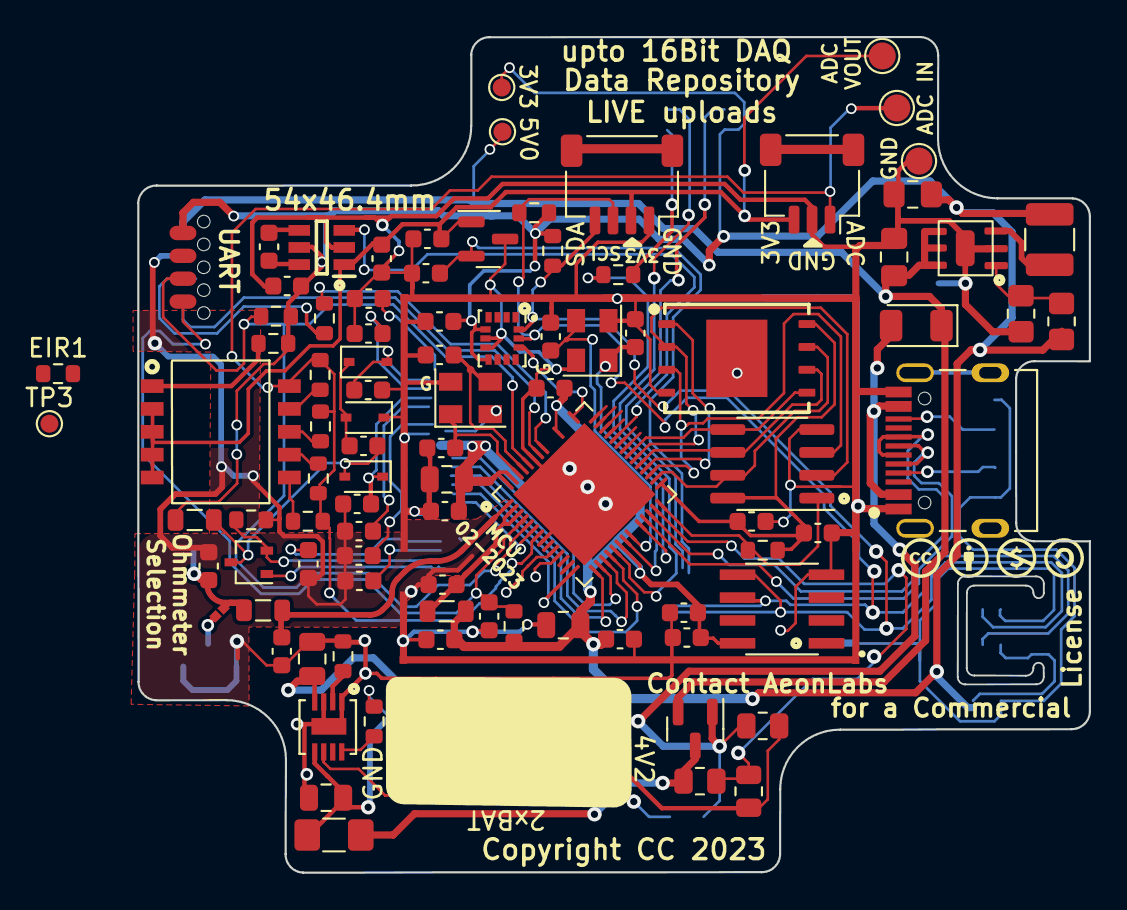
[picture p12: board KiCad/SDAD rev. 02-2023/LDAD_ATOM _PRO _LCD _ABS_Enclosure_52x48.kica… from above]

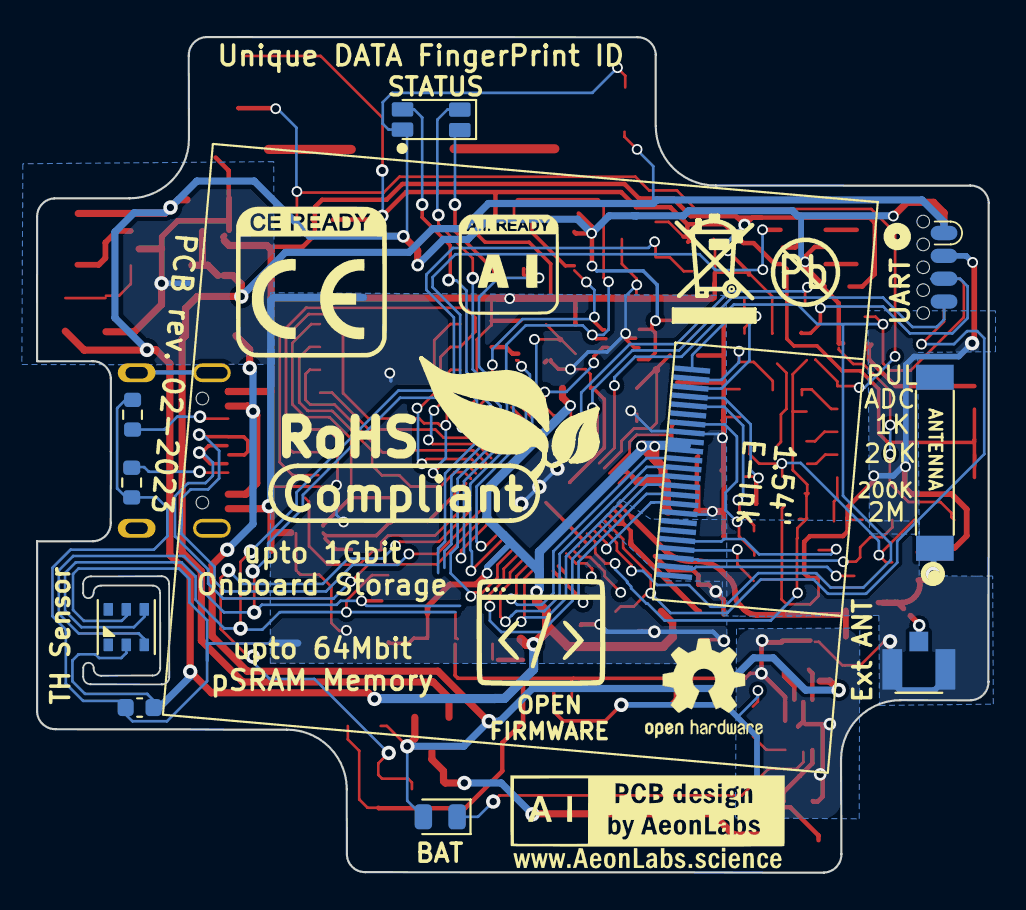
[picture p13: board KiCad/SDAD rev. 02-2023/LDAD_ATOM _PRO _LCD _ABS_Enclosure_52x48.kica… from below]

Board: 2 copper layers, 52.9 x 46.4 mm, 102 parts (13 on the bottom side), 71 nets.

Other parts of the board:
J2: Conn_01x24_Male; 1.54 E-Ink 24 pin LDAD
Sign-PbFree: LOGO_PBFREE
Sign-RecycleBin: LOGO_RECYCLEBIN_1
Sign-RoHS: LOGO_ROHS_1

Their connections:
3V3: J2.15, J2.16; also elsewhere on the board
GDR: J2.2; also elsewhere on the board
GND: J2.8, J2.17; also elsewhere on the board
GPIO8_I2C_SDA: J2.7; also elsewhere on the board
GPIO9_I2C_SCL: J2.6; also elsewhere on the board
LCD2_BUSY_IO01: J2.9; also elsewhere on the board
LCD2_CS_IO10: J2.12; also elsewhere on the board
LCD2_DC_IO13: J2.11; also elsewhere on the board
LCD2_MOSI_IO11: J2.14; also elsewhere on the board
LCD2_RST_IO09: J2.10; also elsewhere on the board
LCD2_SCLK_IO12: J2.13; also elsewhere on the board
unnamed 37: J2.4; also elsewhere on the board
unnamed 38: J2.5; also elsewhere on the board
unnamed 39: J2.18; also elsewhere on the board
unnamed 40: J2.20; also elsewhere on the board
unnamed 41: J2.22; also elsewhere on the board
unnamed 42: J2.24; also elsewhere on the board
PREVGH: J2.21; also elsewhere on the board
PREVGL: J2.23; also elsewhere on the board
RESE: J2.3; also elsewhere on the board

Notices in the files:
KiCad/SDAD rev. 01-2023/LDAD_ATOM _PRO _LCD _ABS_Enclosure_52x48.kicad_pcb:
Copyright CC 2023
